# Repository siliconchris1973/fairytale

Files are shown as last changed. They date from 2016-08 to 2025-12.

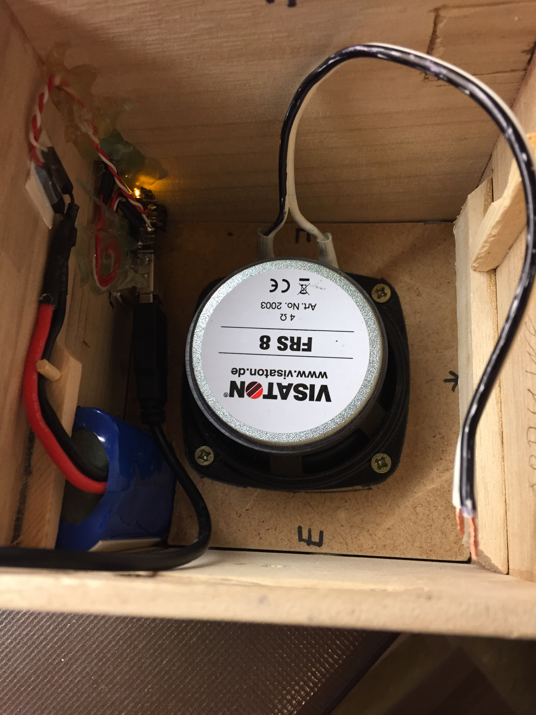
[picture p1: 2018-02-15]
Building Pictures/Inner setup with Loudspeaker, Bat and PowerboostArduino.jpg

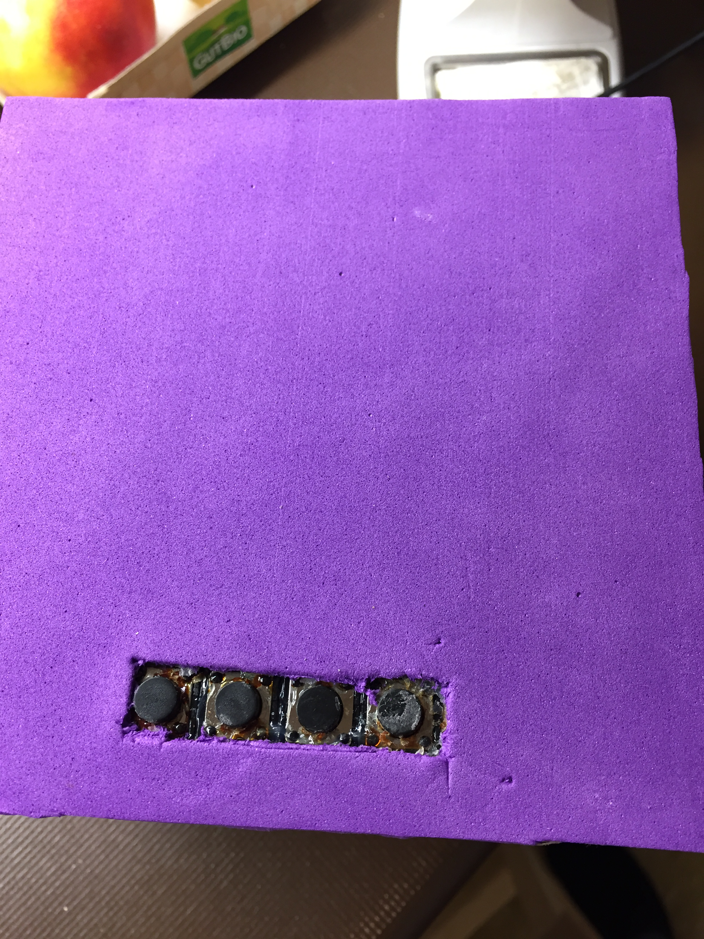
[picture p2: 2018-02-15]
Building Pictures/Top plate with 4 Buttons.jpg

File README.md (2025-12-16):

# fairytale
## Introduction
Fairytale is a mp3-player designed to play audiobooks from an SD Card. The Audiobooks are connected to NFC Tags via the Tag ID, so if you put a Tag on the reader, the corresponding audiobook is played

This tags could for example be attached to little figures - such as Snowhite. Of course you could just put them on little dices or whatever suits you - just keep in mind that my box is supposed to be used by my 4 year old daughter and therefor I use little figures.

The initial version of fairytale ran on an Arduino UNO V3 onto which an Adafruit Music Maker Shield was attached - the code for this version can be found in Arduino_codeline
The version 2 now uses a Raspberry Pi PiCo 2 W (with WLAN) - the code for this version can be found in PiCo_codeline

Furthermore there is a Sunfounder PN532 NFC breakout board attached to it and finally a potentiometer
for volume control and 4 buttons for pause/unpause, next or previous track selection and light effects (turning them on and off).
In version 2 of fairytale an OLED Screen and a RTC clock is included in the setup.
Oh, yes and then of course there is an LED for light effects :-) for warnings and for errors.

## Background
To read the story that initially inspired me to do this project, visit: https://gist.github.com/wkjagt/814b3f62ea03c7b1a765

### Initial (discarded) try Raspberry PI
I started this project off on a Raspberry PI but gave up on it - mainly for three reasons:
1. The Raspberry PI needs way too much time to startup
2. I can't just turn it off because of the danger of damaging the SD Card
3. The volume of the sound output of the RasPi is very limited

All in all, the RasPi approach is not as failsave for a 4 year old, so I gave it up and used the Arduino UNO as the base platform. If you'd nevertheless like to give the RasPi approach a try, you can find the latest state of work in the sub directory RASPI-stuff - be aware though that I never finished it and that there is no guideline on how to build it.

### Version 1 Arduino
NFC controlled MP3 Audiobook Player for my daughter based on an Arduino UNO, Adafruit Music Maker Shield and Sunfounder PN532 NFC Breakout Board.

### Version 2 PiCo
NFC controlled MP3 Audiobook Player for my daughter based on an Raspberry Pi PiCo 2 W, Adafruit Music Maker Shield, Elechouse PN532 NFC Breakout Board V3, DS3231 compatible RTC clokc, SH1106 compatible 128x64 OLED display.

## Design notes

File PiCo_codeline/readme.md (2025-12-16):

# NFC Audio Player für Raspberry Pi Pico
Ein NFC‑gesteuerter Audioplayer auf Basis eines Raspberry Pi Pico, eines Adafruit Music Maker Shields (VS1053 mit SD‑Slot), 
PN532‑NFC‑Reader, SH1106‑OLED und DS3231‑RTC.  
Über einen kleinen HTTP‑Server können im Programmiermodus:
- die RTC Uhr gestellt werden
- ein Verzeichnis unter /audio auf der sd-Karte so umbenannt werden, 
  dass es der Tag UID entspricht - dadurcvh wird dieses Verzeichnis mit dem Tag verknüpft
- Neue Audio-Dateien zu einem aufgelegten Tag auf die SD Karte hochgeladen werden

## Features
- Wiedergabe von MP3‑Dateien über VS1053 vom SD‑Karten‑Dateisystem.
- Steuerung per NFC‑Tags: jedem Tag wird ein „Album“ auf der SD‑Karte zugeordnet - Tag ID = Directory name.
- Programmiermodus (Prog‑Mode) über Hardware‑Schalter und Web‑Interface:
  - WLAN‑Aufbau nur im Prog‑Mode.
  - HTTP‑Upload von Dateien für die aktuell aufgelegte NFC‑UID.
  - Browsen und Löschen von Dateien, Stellen der RTC‑Uhr.
- Persistente Wiedergabestände pro UID (Kapitel, Offset, Volume).
- ID3‑Tag‑Auswertung (Titel, Album, Artist) zur Anzeige im Display.
- Konfigurierbares Debug‑Logging und vielfältige Mock‑Module für Tests (Mock‑NFC, Mock‑Display, Mock‑Audio, Mock‑RTC).

## Hardware
- Raspberry Pi Pico 2 WLAN
- Adafruit Music Maker / VS1053‑Shield 'audio/vs1053.py' (SPI, Audio‑Ausgang) Version von 2017
- PN532‑NFC‑Board (SPI, separates Modul `lib/NFC_PN532.py` plus `nfc/pn532_spi_cargl.py`)
- ZUKÜNFTIG ATTINY, der den PN532 ansteuert und das aktuelle TAG per UART zurückgibt
- SH1106‑OLED (über `display/sh1106_oled.py` und `display/oled_common.py`)
- DS3231‑RTC (I²C) über `rtc/ds3231.py`
- Programmiermodus‑Schalter an `PROG_MODE_PIN` (active low)
- WLAN‑Modul, das durch `net/wifi.py` implementiert wird

Die konkreten Pin‑Belegungen und WLAN‑Zugangsdaten werden in `config.py` konfiguriert.

## Projektstruktur (wichtige Module)
- main.py  
  Initialisiert Hardware, konfiguriert alle Komponenten und übergint sie 
  an den PlayerController. Überwacht den Prog-Mode Butzton und steuert den 
  controller nur an, wenn nicht prog_mode. 
- net/http_server.py / net/web.py
  Kleiner nicht‑blockierender HTTP‑Server mit Endpunkten:
  - `/` – Startseite mit Status, Upload‑Info und Links.
  - `/upload` – GET zeigt Formular, POST nimmt Dateien an (nur wenn `allowed_uid` gesetzt).
  - `/browse` – Verzeichnislisting (Pfad über `path`‑Query).
  - `/delete` – Datei löschen.
  - `/time` – RTC anzeigen/setzen.
  Im Prog-Mode wird von http_server.py der web serbver aufgebaut und von web.py
  die Erzeugung neuer Alben auf der SD Karte und das setzen der RTC Uhr übernommen.
- controller.py
  Zentrale Audio-Ausgabe: kümmert sich um Play/Pause/Next/Prev und die Ausgabe 
  des Fortschritts, der Lautstärke und der Uhr auf dem Display.
  Macxht keine direkte NFC Überprüfung, sondern nutzt dafür ein Trigger-System. 
  Dieses übergibt eine UID, dann play start oder ein stop-signalö, (derzeit Button, 
  zuküünftig Tag weg) für Play Stop.
- storage.py
  Kapselt Dateisystem‑Operationen, u.a. Dateilisten für eine UID, Laden/Speichern von UID‑State, 
  Speichern hochgeladener Dateien.
- vs1053.py / audio.py
  Abstraktion für Audiowiedergabe: `start(path, offset)`, `feed()`, `stop()`, `pause()`, `resume()`, 
  `set_volume()` und Eigenschaften `total_bytes`, `pos_bytes`.
- lib/NFC_PN532.py / nfc/pn532_spi_cargl.py
  Zugriff auf PN532; mindestens `init()` und `read_uid(timeout_ms=...)` werden genutzt.
- display/oled_common.py, display/sh1106.py, display/sh1106_oled.py, display/touch_display.py  
  Display‑Abstraktion, die Funktionen wie `show_status`, `show_play`, `show_stop`, `show_idle`, 
  `show_prog`, `set_time`, `set_date`, `set_volume`, `set_progress_text` etc. bereitstellt.
- buttons.py
  Liest Taster mit Entprellung und liefert Events (`play_pause`, `next`, `prev`, `stop`) über `poll()`. 
  Optionaler Dispatcher.
- volume.py
  Gibt pro Änderung ein Lautstärke‑Delta als Prozentwert zurück (`changed()`) und speichert letzten Wert.
- `ds3231.py`, `rtc.py` / `mock_rtc.py`  
  RTC‑Abstraktion; `rtc.now()` liefert `(y, m, d, wd, hh, mm, ss)`.
- id3.py
  Liest einfache ID3‑Tags aus MP3‑Dateien und liefert ein Dictionary mit `title`, `album`, `artist`, `track` etc.
- config.py
  Zentrale Konfigurationswerte (Pins, Pfade, Debug‑Flags, Prog‑Mode‑Quelle, Zeit‑Konstanten für NFC‑Checks usw.).
- diverse trigger-Dateien
  abstrahiert die Übergabe des Tags von NFC an controller und das setzen eines Stop Events (derzeit per Button)
  um das Beenden der Wiedergabe zu signalisieren

## Installation
1. Repository klonen und Projektdateien auf den Pico (MicroPython) kopieren.
2. `config.py` anpassen:
   - WLAN‑Parameter (SSID, Passwort).
   - Dateipfade (z. B. `AUDIO_ROOT`, `STATE_DIR`).
   - `PROG_MODE_PIN` und `PROG_MODE_SOURCE` („PIN“, „ACTIVE“, „INACTIVE“).
3. SD‑Karte vorbereiten:
   - Basis‑Verzeichnisstruktur wie in `storage.py` vorgesehen anlegen (z. B. pro UID ein Unterordner).
   - Test‑MP3‑Dateien einspielen.
4. Hardware wie in der Konfiguration verdrahten (SPI, I²C, GPIOs).

## Nutzung
### Normalmodus (Audio‑Player)
- Gerät starten.
- OLED zeigt Begrüßung und „Show Tag to play“.
- NFC‑Tag auflegen:
  - NFC IMplementeiorung erkennt neue UID via `nfc.read_uid()` und starte Audfio im Controller.
- Steuerung:
  - Taster: `play_pause`, `next`, `prev`, `stop` (via `buttons.poll()`).
  - Rotary/Volume‑Input: Änderung führt zu `audio.set_volume()` und Anzeige im OLED.
- Fortschritt:
  - `audio.feed()` wird im Hauptloop regelmäßig aufgerufen; Prozentanzeige basiert auf `pos_bytes`/`total_bytes`.
- Tag‑Präsenz wird derzeit nicht geprüft, wird zuküpnftig durch externen MicroController realisiert:
  - Wenn auf ATTINY implementiert, dann wird per UART Tag Weg signalisiert, indem die Tag ID auf NOne gesetzt wird.
    Dies stoppt dann die Audio-Ausgabe.

### Programmiermodus und HTTP‑Upload
- PROG‑Schalter aktivieren (active low, abhängig von `PROG_MODE_SOURCE`).
- Beim Wechsel in den Prog‑Mode:
  - WLAN wird aufgebaut (`wifi.connect()`), IP‑Adresse im Display angezeigt.
  - HTTP‑Server wird „gearmed“ und an `0.0.0.0:UPLOAD_PORT` gebunden.
- NFC‑Tag im Prog‑Mode auflegen:
  - `nfc.read_uid()` im Main Loop liest UID, `active_uid` wird gesetzt und an den HTTP‑Server über `http.arm(uid)` übergeben.
  - Upload ist nun für diese UID freigeschaltet (`allowed_uid`).
- Browser:
  - IP des Geräts im Browser öffnen (z. B. `http://<pico-ip>:<UPLOAD_PORT>/`).
  - Dateien für diese UID hochladen, Verzeichnisse durchsuchen, Dateien löschen und RTC stellen.
- Beim Verlassen des Prog‑Mode:
  - Upload wird deaktiviert, HTTP‑Server optional „disarmed“ und WLAN getrennt.

## Entwicklungs‑ und Testunterstützung
- Mock‑Module (`mock_nfc.py`, `mock_display.py`, `mock_audio.py`, `mock_rtc.py`) erlauben lokale Tests ohne echte Hardware.
- Umfangreiche Debug‑Ausgaben über `_DEBUG_*`‑Flags in `config.py` helfen beim Tracing von NFC‑Events, HTTP‑Requests, Audio‑Timing etc.

## Lizenz
Creative Commons (CC) Lizenz

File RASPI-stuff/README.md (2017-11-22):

# fairytale
## Introduction
Fairytale is a node.js server application designed to play mp3 files (such as
  but of course not limited to audiobooks). You can either control it using
  a rather ugly HTML interface or, which is the intended usage, by RFID or NFC tags.

## Background
To read the story that inspired me to do this, visit: https://gist.github.com/wkjagt/814b3f62ea03c7b1a765

## Installation
To get going issue:

     git clone https://github.com/siliconchris1973/fairytale

     cd fairytale
     cd fairytale-app
     mkdir data/Media
     mkdir data/TagDB
     mkdir data/Cover
     mkdir data/Cover/icon
     mkdir data/Cover/small
     mkdir data/Cover/normal
     npm install

## Dependencies
fairytale depends on
- MPlayer to play the audio files
- libnfc to read the RFID / NFC tags
- node-nfc-daemon to expose libnfc as a websocket

### Install MPlayer
#### Debian (and derivates like Raspbian)
     sudo apt-get install mplayer

#### Mac OS X
     brew install mplayer

### Install libnfc
#### Raspbian
You can either install the libnfc from the distro or compile it from source.
To install the nfc library bundled with Raspbian (Jessie but probably stretch also):

     sudo apt-get libnfc

To compile it from the git source:

     cd ~
     wget http://dl.bintray.com/nfc-tools/sources/libnfc-1.7.1.tar.bz2
     tar -xf libnfc-1.7.1.tar.bz2  
     cd libnfc-1.7.1
     ./configure --prefix=/usr --sysconfdir=/etc
     make
     sudo make install

Create a configuration file:

     cd /etc
     sudo mkdir nfc
     sudo vi /etc/nfc/libnfc.conf

Content of the configuration file (for SPI connection on a Raspberry Pi) is like follows:

     # Allow device auto-detection (default: true)
     # Note: if this auto-detection is disabled, user has to set manually a device
     # configuration using file or environment variable
     allow_autoscan = true

     # Allow intrusive auto-detection (default: false)
     # Warning: intrusive auto-detection can seriously disturb other devices
     # This option is not recommended, user should prefer to add manually his device.
     allow_intrusive_scan = false

     # Set log level (default: error)
     # Valid log levels are (in order of verbosity): 0 (none), 1 (error), 2 (info), 3 (debug)
     # Note: if you compiled with --enable-debug option, the default log level is "debug"
     log_level = 1

     # Manually set default device (no default)
     # To set a default device, you must set both name and connstring for your device
     # Note: if autoscan is enabled, default device will be the first device available in device list.
     device.name = "_PN532_SPI"
     device.connstring = "pn532_spi:/dev/spidev0.0:500000"
     #device.name = "_PN532_I2c"
     #device.connstring = "pn532_i2c:/dev/i2c-1"

#### MacOS X
If you happen to be doing all this on OS X you _may_ need to accept the developers
license for Xcode. Agree to the license terms by executing (in a shell, of
course):

     sudo xcodebuild -license

For libnfc to compile on Mac OS X you will need doxygen, which I recommend you install via brew

     brew install doxygen

Now cd to a convenient directory where you want libnfc source to reside and hack in:

     git clone https://github.com/nfc-tools/libnfc.git
     cd libnfc
     ./configure --enable-doc
     make
     sudo make install

This will install libnfc in /usr/local directory, which I usually do not find to be convenient on OS X, as I can't easily remove it if wanted. Usually I'd prefer to install it in /opt/libnfc, but I couldn't find a way to get node-nfc-daemon to compile on my Mac with libnfc installed below opt, so I put it in /usr/local

Further information on libnfc can be found at
 http://nfc-tools.org/index.php?title=Libnfc

### Install node-nfc-daemon
For information on node-nfc-daemon setEncoding
  https://www.npmjs.com/package/nfc-daemon

#### Raspbian / Mac OS X
     yarn global add nfc-daemon

## Running
fairytale is composed of 6 different services:
1. app.js - main server application
2. player.js - the mp3 player
3. tagDbService.js - an interface to the stored tags with meta data on the mp3 files
4. nfcReader - the nfc reader service
5. fileService.js - upload files (optional you can also do this manually)
6. ledService - drives 3 colored LEDs (optional)

All components are in their respective subdirectory with [App-Name]-app as the directory name.

### Mandatory components
#### app.js
This is the main component. It listens on port 3000 and exposes it's endpoints to /api/v1/... for json and html clients.

To start up the main application with nodemon monitoring execute:

     npm start

To start it manually execute:

     node app.js

#### player.js
The MP3 Player application. It listens on port 3001 and exposes it's endpoint to /api/v1/player for json and html clients.

To start the mp3 player with nodemon monitoring execute:

     npm start

Without nodemon:

     node player.js

#### tagDbService.js
An interface to stored json files that contain the necessary meta data on the nfc tags.
Within each json file a nfc tag and the corresponding mp3 files are described.

To start the TagDB service with nodemon monitoring execute:

     npm start

Without nodemon:

     node tagDbService.js

#### nfcService.js
The RFID and NFC tag reader. It listens on port 3003 and exposes it's endpoint to /api/v1/rfid for json and html clients.

To start the RFID and NFC Reader with nodemon monitoring execute:

     npm start

Without nodemon:

     node nfcService.js

### Optional components
#### ledService.js
The driver for the leds. It listens on port 3005 and exposes it's endpoint to /api/v1/rfid for json and html clients.

To start the LED Service with nodemon monitoring execute:

     npm start

Without nodemon:

     node ledService.js

#### fileService.js
The file uploader only exposes a html formm at the moment and is available on port 3002 at /api/v1/file
To start the optional fileService (for uploading files) execute:

     node fileService.js

## interacting with the application
### via curl on command line

     curl -X GET -H "Content-type: application/json" -H "Accept: application/json"  "http://deepthought.local:3002/api/v1/player/{"id":"0443e222e74c81"}"

## Create Content to play
For the play to actually play a file, two things need to be done:
1. Create a JSON File with information on the mp3 file you want to hear, when you put the tag on the reader
2. Copy the mp3 files in a specific directory.

A typical json file looks like follows:

75EDB4.json:

       {
        "tagdata": {
          "TagChecksum": "0x23",
          "TagId": "75EDB4",
          "TagPreTag": "0xf00",
          "TagRawData": "0F0075EDB423"
        },
        "MediaTitle": "Frederick",
        "MediaType": "Hoerspiel",
        "MediaGenre": "Kindergeschichte",
        "MediaDescription": "Ein Hörspiel mit Musik zu Frederick der kleinen Maus",
        "TrackCount": [
          {"disk": "1", "tracks": "1"}
        ],
        "DiskCount": "1",
        "MediaFiles": [{
          "disk": "1",
          "part": "1",
          "id": "75EDB4:d1:p1",
          "name": "Frederick.mp3",
          "path": "Media/Disk_1/Frederick.mp3",
          "lastposition": "-1",
          "playcount": "0",
          "size": "24M"
        }],
        "MediaPicture": [{
          "pic": "1",
          "name": "Frederick.jpg",
          "path": "Cover/normal/Frederick.jpg"
        }]
       }

As you can see, you can have multiple mp3 files associated with a tag and the player
will play all files in the given order - you can also split files in disks.

To make registering a new tag with it's files easier, I will include a page to aid in the process.
Currently, when you have a new tag and want to associate it with mp3-files you will need
to do the following:

- copy/create a json file in the data/TagDB directory. The name of the file needs to match the UUID
- make a new directory with the UUID of the nfc tag below data/Media - the directory name should be all upper case
- copy all mp3-files in the sub directories you used within the json file in the path section.

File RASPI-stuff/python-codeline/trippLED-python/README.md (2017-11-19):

# trippLED
# # Description
A simple python app to drive 3 differntly colored leds (here red, green and blue) via a REST API.

# Installation
Is installed automatically with the rest of the fairytale applications, but there are a few Dependencies.

## Dependencies:
### flask
sudo pip install flask

### flask-restful
sudo pip install flask-restful

# Run
python cycLED.py

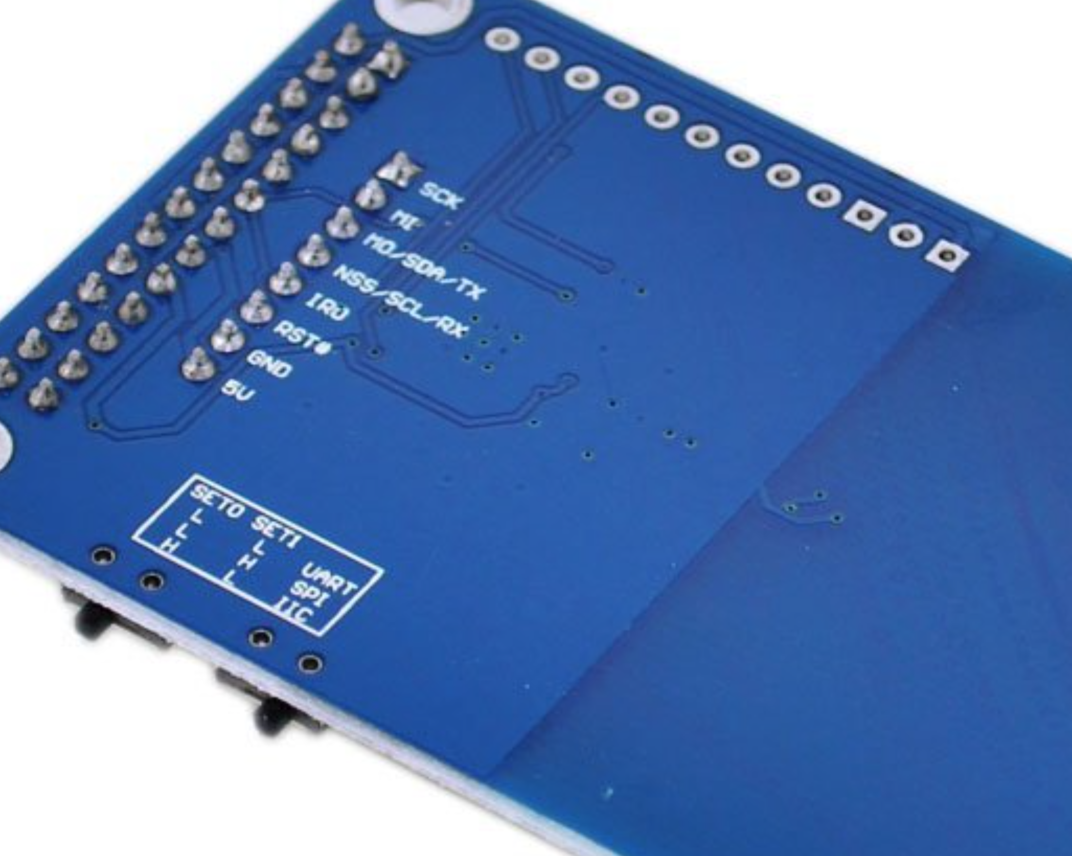
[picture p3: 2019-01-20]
3rd Party Schematics/Pinout Sunfounder PN532 NFC module.png

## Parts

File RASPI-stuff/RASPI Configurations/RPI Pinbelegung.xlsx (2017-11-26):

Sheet: Pinbelegung Template
Anschlussplan für Verbindung Raspberry PI mit Nokia5110, Tasterleiste und Distance
 |  |  |  |  | Pins von |  |  |  | oben |  | zählen
Zusatz |  | Kabel | Anschluss- |  |  | Raspberry PI |  |  |  |  |  |  |  |  |  | Anschluss- | Kabel |  | Zusatz |  |  |  |  | Farben | Anzahl belegter Ports |  |  |  |  | Kabel linke Seite |  |  |  |  |  |  |  |  |  |  |  |  | Kabel rechte Seite
Info | Ziel | Farbe | Ziel / Typ | 7 |  |  |  | 5 |  |  | 4 |  |  |  | 5 | Ziel / Typ | Farbe | Ziel | Info |  |  |  | Bauteile | Kabel- | Linke Seite | Rechte Seite | GPIO links | GPIO rechts | Summe | 1 | 0 | 0 | 1 | 0 | 0 | 1 | 0 | 0 | 0 | 0 | 0 | 0 | 0 | 0 | 0 | 0 | 0 | 1 | 1 | 0 | 1 | 1 | 0 | 0 | 0 | Text
 |  |  |  |  |  |  | Typ | GPIO | Pin # |  | GPIO | Typ |  |  |  |  |  |  |  |  |  |  | + Geräte | Farben | 7 | 5 | 5 | 4 |  | Rot | Orange | Gelb | Grün | Blau | Lila | Weiss | Grau | Braun | Schwarz | Gestreift | mit Naht | Anders | Rot | Orange | Gelb | Grün | Blau | Lila | Weiss | Grau | Braun | Schwarz | Gestreift | mit Naht | Anders
Plus Backlight | Nokia5110 | Rot | VCC 3.3v | <-- | 1 | v | 3.3v |  | 1 | 2 |  | 5v | v |  |  |  |  |  |  | 1 | 20 | 1 | Nokia5110 | Rot | 1 | 0 | 0 | 0 | 1 | 1 | 0 | 0 | 0 | 0 | 0 | 0 | 0 | 0 | 0 | 0 | 0 | 0 | 0 | 0 | 0 | 0 | 0 | 0 | 0 | 0 | 0 | 0 | 0 | 0 | 0 | 1 Rot
 |  |  |  |  |  | I2C | SDA | 02 | 3 | 4 |  | 5v | v |  |  |  |  |  |  | 2 | 19 | 2 | Tasterleiste | Orange | 0 | 0 | 0 | 0 | 0 | 0 | 0 | 0 | 0 | 0 | 0 | 0 | 0 | 0 | 0 | 0 | 0 | 0 | 0 | 0 | 0 | 0 | 0 | 0 | 0 | 0 | 0 | 0 | 0 | 0 | 0 | keines Orange
 |  |  |  |  |  |  | SCL | 03 | 5 | 6 |  | GND | g | 3 | --> | Ground | Schwarz | Nokia5110 |  | 3 | 18 | 3 | Distance | Gelb | 0 | 1 | 0 | 0 | 0 | 0 | 0 | 0 | 0 | 0 | 0 | 0 | 0 | 0 | 0 | 0 | 0 | 0 | 0 | 0 | 0 | 0 | 0 | 0 | 0 | 0 | 0 | 1 | 0 | 0 | 0 | keines Gelb
 |  |  |  |  |  |  |  | 04 | 7 | 8 | 14 | TXD | UART |  |  |  |  |  |  | 4 | 17 | 4 | LED | Grün | 0 | 0 | 0 | 0 | 1 | 0 | 0 | 0 | 0 | 0 | 0 | 0 | 0 | 0 | 0 | 0 | 0 | 0 | 0 | 0 | 0 | 0 | 0 | 0 | 0 | 0 | 0 | 0 | 0 | 0 | 0 | 1 Grün
 |  |  |  |  |  | g | GND |  | 9 | 10 | 15 | RXD |  |  |  |  |  |  |  | 5 | 16 | 5 | Schalter | Blau | 0 | 0 | 0 | 0 | 0 | 0 | 0 | 0 | 0 | 0 | 0 | 0 | 0 | 0 | 0 | 0 | 0 | 0 | 0 | 0 | 0 | 0 | 0 | 0 | 0 | 0 | 0 | 0 | 0 | 0 | 0 | keines Blau
 | Distance | Weiss | Trigger | <-- | 6 |  |  | 17 | 11 | 12 | 18 | PCM_CLK |  | 6 | --> | Echo | Braun | Distance |  | 6 | 15 | 6 | Poti | Lila | 1 | 1 | 1 | 1 | 1 | 0 | 0 | 0 | 0 | 0 | 0 | 1 | 0 | 0 | 0 | 0 | 0 | 0 | 0 | 0 | 0 | 0 | 0 | 0 | 0 | 0 | 1 | 0 | 0 | 0 | 0 | 1 Lila
 |  |  |  |  |  |  |  | 27 | 13 | 14 |  | GND | g |  |  |  |  |  |  | 7 | 14 | 7 | VCC 5v | Weiss | 0 | 0 | 0 | 0 | 2 | 0 | 0 | 0 | 0 | 0 | 0 | 0 | 0 | 0 | 0 | 0 | 0 | 0 | 0 | 0 | 0 | 0 | 0 | 0 | 0 | 0 | 0 | 0 | 0 | 0 | 0 | 2 Weiss
 |  |  |  |  |  |  |  | 22 | 15 | 16 | 23 |  |  | 8 | --> | DC | Weiss | Nokia5110 |  | 8 | 13 | 8 | VCC 3.3v | Grau | 0 | 1 | 0 | 1 | 0 | 0 | 0 | 0 | 0 | 0 | 0 | 0 | 0 | 0 | 0 | 0 | 0 | 0 | 0 | 0 | 0 | 0 | 0 | 0 | 1 | 0 | 0 | 0 | 0 | 0 | 0 | keines Grau
 |  |  |  |  |  | v | 3.3v |  | 17 | 18 | 24 |  |  | 9 | --> | Reset | Lila | Nokia5110 | RST | 9 | 12 | 9 | Reset | Braun | 0 | 1 | 0 | 1 | 1 | 0 | 0 | 0 | 0 | 0 | 0 | 0 | 0 | 0 | 0 | 0 | 0 | 0 | 0 | 0 | 0 | 0 | 0 | 1 | 0 | 0 | 0 | 0 | 0 | 0 | 0 | 1 Braun
 | Nokia5110 | Grün | DIN | <-- | 10 | SPI | MOSI | 10 | 19 | 20 |  | GND | g |  |  |  |  |  |  | 10 | 11 | 10 | Power | Schwarz | 1 | 0 | 1 | 0 | 1 | 0 | 0 | 0 | 1 | 0 | 0 | 0 | 0 | 0 | 0 | 0 | 0 | 0 | 0 | 0 | 0 | 0 | 0 | 0 | 0 | 0 | 0 | 0 | 0 | 0 | 0 | 1 Schwarz
 |  |  |  |  |  |  | MISO | 09 | 21 | 22 | 25 |  |  |  |  |  |  |  |  | 11 | 10 | 11 | Ground | Gestreift | 0 | 0 | 0 | 0 | 0 | 0 | 0 | 0 | 0 | 0 | 0 | 0 | 0 | 0 | 0 | 0 | 0 | 0 | 0 | 0 | 0 | 0 | 0 | 0 | 0 | 0 | 0 | 0 | 0 | 0 | 0 | keines Gestreift
CLK | Nokia5110 | Blau | Clock | <-- | 12 |  | SCLK | 11 | 23 | 24 | 08 | CE0 | SPI | 12 | --> | CE | Grau | Nokia5110 |  | 12 | 9 | 12 | Daten | mit Naht | 1 | 1 | 1 | 1 | 0 | 0 | 0 | 0 | 0 | 1 | 0 | 0 | 0 | 0 | 0 | 0 | 0 | 0 | 0 | 0 | 0 | 0 | 0 | 0 | 0 | 1 | 0 | 0 | 0 | 0 | 0 | keines mit Naht
 |  |  |  |  |  | g | GND |  | 25 | 26 | 07 | CE1 |  |  |  |  |  |  |  | 13 | 8 | 13 | Clock | Anders | 0 | 0 | 0 | 0 | 0 | 0 | 0 | 0 | 0 | 0 | 0 | 0 | 0 | 0 | 0 | 0 | 0 | 0 | 0 | 0 | 0 | 0 | 0 | 0 | 0 | 0 | 0 | 0 | 0 | 0 | 0 | keines Anders
 |  |  |  |  |  |  | ID_SD |  | 27 | 28 |  | ID_SC |  |  |  |  |  |  |  | 14 | 7 | 14 | Backlight |  | 0 | 0 | 0 | 0 |  |  |  |  |  |  |  |  |  |  |  |  |  |  |  |  |  |  |  |  |  |  |  |  |  |  |  | 1 Rot, keines Orange, keines Gelb, 1 Grün, keines Blau, 1 Lila, 2 Weiss, keines Grau, 1 Braun, 1 Schwarz, keines Gestreift, keines mit Naht und keines Anders
 |  |  |  |  |  |  |  | 05 | 29 | 30 |  | GND | g |  |  |  |  |  |  | 15 | 6 | 15 | Trigger |  | 0 | 0 | 0 | 0
 |  |  |  |  |  |  |  | 06 | 31 | 32 | 12 |  |  |  |  |  |  |  |  | 16 | 5 | 16 | Echo |  | 0 | 0 | 0 | 0
 |  |  |  |  |  |  |  | 13 | 33 | 34 |  | GND | g |  |  |  |  |  |  | 17 | 4 | 17 |  |  | 0 | 0 | 0 | 0
Funktion | Tasterleiste | Braun | Power | <-- | 18 |  |  | 19 | 35 | 36 | 16 |  |  |  |  |  |  |  |  | 18 | 3 | 18 |  |  | 1 | 0 | 1 | 0
Funktion | Tasterleiste | Braun | Reset | <-- | 19 |  |  | 26 | 37 | 38 | 20 |  |  |  |  |  |  |  |  | 19 | 2 | 19 |  |  | 1 | 0 | 1 | 0
 | Tasterleiste | Schwarz | Ground | <-- | 20 | g | GND |  | 39 | 40 | 21 |  |  |  |  |  |  |  |  | 20 | 1 | 20 |  |  | 1 | 0 | 0 | 0
 |  |  |  |  |  | USB und LAN Anschlüsse
Zum Anschluss des Nokia5110 an den Raspberry PI werden 12 Kabel benötigt (7 auf der linken und 5 auf der rechten Seite) und 9 GPIO-Ports sind nach Anschluss belegt. Von den 12 Kabeln sind 1 Rot, keines Orange, keines Gelb, 1 Grün, keines Blau, 1 Lila, 2 Weiss, keines Grau, 1 Braun, 1 Schwarz, keines Gestreift, keines mit Naht und keines Anders farbig |  |  |  |  |  |  |  |  |  |  |  |  |  |  |  |  |  |  |  |  |  |  | TRX
 |  |  |  |  |  |  |  |  |  |  |  |  |  |  |  |  |  |  |  |  |  |  | RXD
 |  |  |  |  |  |  |  |  |  |  |  |  |  |  |  |  |  |  |  |  |  |  | SDA
 |  |  |  |  |  |  |  |  |  |  |  |  |  |  |  |  |  |  |  |  |  |  | SCL
 |  |  |  |  |  |  |  |  |  |  |  |  |  |  |  |  |  |  |  |  |  |  | DC
 |  |  |  |  |  |  |  |  |  |  |  |  |  |  |  |  |  |  |  |  |  |  | CE
 |  |  |  |  |  |  |  |  |  |  |  |  |  |  |  |  |  |  |  |  |  |  | DIN
 |  |  |  |  |  |  |  |  |  |  |  |  |  |  |  |  |  |  |  |  |  |  | PCM

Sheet: Pinbelegung Nokia5110-NFC532
Anschlussplan für Verbindung Raspberry PI mit NFC532 und Nokia5110
 |  |  |  |  | Pins von |  |  |  | oben |  | zählen
Zusatz |  | Kabel | Anschluss- |  |  | Raspberry PI |  |  |  |  |  |  |  |  |  | Anschluss- | Kabel |  | Zusatz |  |  |  |  | Farben | Anzahl belegter Ports |  |  |  |  | Kabel linke Seite |  |  |  |  |  |  |  |  |  |  |  |  | Kabel rechte Seite
Info | Ziel | Farbe | Ziel / Typ | 7 |  |  |  | 5 |  |  | 6 |  |  |  | 9 | Ziel / Typ | Farbe | Ziel | Info |  |  |  | Bauteile | Kabel- | Linke Seite | Rechte Seite | GPIO links | GPIO rechts | Summe | 1 | 1 | 0 | 0 | 0 | 0 | 0 | 0 | 0 | 0 | 0 | 0 | 0 | 1 | 1 | 0 | 0 | 0 | 0 | 0 | 0 | 1 | 1 | 0 | 0 | 0 | Text
 |  |  |  |  |  |  | Typ | GPIO | Pin # |  | GPIO | Typ |  |  |  |  |  |  |  |  |  |  | + Geräte | Farben | 7 | 9 | 5 | 6 |  | Rot | Orange | Gelb | Grün | Blau | Lila | Weiss | Grau | Braun | Schwarz | Gestreift | mit Naht | Anders | Rot | Orange | Gelb | Grün | Blau | Lila | Weiss | Grau | Braun | Schwarz | Gestreift | mit Naht | Anders
 | Nokia5110 | Orange | VCC 3.3v | <-- | 1 | v | 3.3v |  | 1 | 2 |  | 5v | v | 1 | --> | VCC 5v | Rot | NFC532 |  | 1 | 20 | 1 | NFC532 | Rot | 1 | 1 | 0 | 0 | 2 | 0 | 1 | 0 | 0 | 0 | 0 | 0 | 0 | 0 | 0 | 0 | 0 | 0 | 1 | 0 | 0 | 0 | 0 | 0 | 0 | 0 | 0 | 0 | 0 | 0 | 0 | 2 Rot
 |  |  |  |  |  | I2C | SDA | 02 | 3 | 4 |  | 5v | v |  |  |  |  |  |  | 2 | 19 | 2 | Nokia5110 | Orange | 0 | 0 | 0 | 0 | 2 | 0 | 0 | 0 | 0 | 0 | 0 | 0 | 0 | 0 | 0 | 0 | 0 | 0 | 0 | 0 | 0 | 0 | 0 | 0 | 0 | 0 | 0 | 0 | 0 | 0 | 0 | 2 Orange
 |  |  |  |  |  |  | SCL | 03 | 5 | 6 |  | GND | g | 3 | --> | Ground | Schwarz |  | für alles | 3 | 18 | 3 |  | Gelb | 0 | 1 | 0 | 0 | 0 | 0 | 0 | 0 | 0 | 0 | 0 | 0 | 0 | 0 | 0 | 0 | 0 | 0 | 0 | 0 | 0 | 0 | 0 | 0 | 0 | 0 | 0 | 1 | 0 | 0 | 0 | keines Gelb
 |  |  |  |  |  |  |  | 04 | 7 | 8 | 14 | TXD | UART |  |  |  |  |  |  | 4 | 17 | 4 | LED | Grün | 0 | 0 | 0 | 0 | 0 | 0 | 0 | 0 | 0 | 0 | 0 | 0 | 0 | 0 | 0 | 0 | 0 | 0 | 0 | 0 | 0 | 0 | 0 | 0 | 0 | 0 | 0 | 0 | 0 | 0 | 0 | keines Grün
 |  |  |  |  |  | g | GND |  | 9 | 10 | 15 | RXD |  |  |  |  |  |  |  | 5 | 16 | 5 | Schalter | Blau | 0 | 0 | 0 | 0 | 0 | 0 | 0 | 0 | 0 | 0 | 0 | 0 | 0 | 0 | 0 | 0 | 0 | 0 | 0 | 0 | 0 | 0 | 0 | 0 | 0 | 0 | 0 | 0 | 0 | 0 | 0 | keines Blau
 |  |  |  |  |  |  |  | 17 | 11 | 12 | 18 | PCM_CLK |  |  |  |  |  |  |  | 6 | 15 | 6 | Poti | Lila | 0 | 0 | 0 | 0 | 0 | 0 | 0 | 0 | 0 | 0 | 0 | 0 | 0 | 0 | 0 | 0 | 0 | 0 | 0 | 0 | 0 | 0 | 0 | 0 | 0 | 0 | 0 | 0 | 0 | 0 | 0 | keines Lila
 |  |  |  |  |  |  |  | 27 | 13 | 14 |  | GND | g |  |  |  |  |  |  | 7 | 14 | 7 | VCC 5v | Weiss | 0 | 0 | 0 | 0 | 0 | 0 | 0 | 0 | 0 | 0 | 0 | 0 | 0 | 0 | 0 | 0 | 0 | 0 | 0 | 0 | 0 | 0 | 0 | 0 | 0 | 0 | 0 | 0 | 0 | 0 | 0 | keines Weiss
 |  |  |  |  |  |  |  | 22 | 15 | 16 | 23 |  |  | 8 | --> | DC | Braun | Nokia5110 |  | 8 | 13 | 8 | VCC 3.3v | Grau | 0 | 1 | 0 | 1 | 0 | 0 | 0 | 0 | 0 | 0 | 0 | 0 | 0 | 0 | 0 | 0 | 0 | 0 | 0 | 0 | 0 | 0 | 0 | 0 | 0 | 0 | 1 | 0 | 0 | 0 | 0 | keines Grau
 |  |  |  |  |  | v | 3.3v |  | 17 | 18 | 24 |  |  | 9 | --> | Reset | Orange | Nokia5110 |  | 9 | 12 | 9 | Reset | Braun | 0 | 1 | 0 | 1 | 1 | 0 | 0 | 0 | 0 | 0 | 0 | 0 | 0 | 0 | 0 | 0 | 0 | 0 | 0 | 1 | 0 | 0 | 0 | 0 | 0 | 0 | 0 | 0 | 0 | 0 | 0 | 1 Braun
 | Nokia5110 | Rot | DIN DataIn | <-- | 10 | SPI | MOSI | 10 | 19 | 20 |  | GND | g |  |  |  |  |  |  | 10 | 11 | 10 | Power | Schwarz | 1 | 0 | 1 | 0 | 1 | 1 | 0 | 0 | 0 | 0 | 0 | 0 | 0 | 0 | 0 | 0 | 0 | 0 | 0 | 0 | 0 | 0 | 0 | 0 | 0 | 0 | 0 | 0 | 0 | 0 | 0 | 1 Schwarz
 |  |  |  |  |  |  | MISO | 09 | 21 | 22 | 25 |  |  |  |  |  |  |  |  | 11 | 10 | 11 | Ground | Gestreift | 0 | 0 | 0 | 0 | 0 | 0 | 0 | 0 | 0 | 0 | 0 | 0 | 0 | 0 | 0 | 0 | 0 | 0 | 0 | 0 | 0 | 0 | 0 | 0 | 0 | 0 | 0 | 0 | 0 | 0 | 0 | keines Gestreift
 | Nokia5110 | Lila | CLK | <-- | 12 |  | SCLK | 11 | 23 | 24 | 08 | CE0 | SPI | 12 | --> | CS bzw. CE | Blau | Nokia5110 |  | 12 | 9 | 12 | Daten | mit Naht | 1 | 1 | 1 | 1 | 0 | 0 | 0 | 0 | 0 | 0 | 1 | 0 | 0 | 0 | 0 | 0 | 0 | 0 | 0 | 0 | 0 | 0 | 1 | 0 | 0 | 0 | 0 | 0 | 0 | 0 | 0 | keines mit Naht
 |  |  |  |  |  | g | GND |  | 25 | 26 | 07 | CE1 |  |  |  |  |  |  |  | 13 | 8 | 13 | Clock | Anders | 0 | 0 | 0 | 0 | 0 | 0 | 0 | 0 | 0 | 0 | 0 | 0 | 0 | 0 | 0 | 0 | 0 | 0 | 0 | 0 | 0 | 0 | 0 | 0 | 0 | 0 | 0 | 0 | 0 | 0 | 0 | keines Anders
 |  |  |  |  |  |  | ID_SD |  | 27 | 28 |  | ID_SC |  |  |  |  |  |  |  | 14 | 7 | 14 | Backlight |  | 0 | 0 | 0 | 0 |  |  |  |  |  |  |  |  |  |  |  |  |  |  |  |  |  |  |  |  |  |  |  |  |  |  |  | 2 Rot, 2 Orange, keines Gelb, keines Grün, keines Blau, keines Lila, keines Weiss, keines Grau, 1 Braun, 1 Schwarz, keines Gestreift, keines mit Naht und keines Anders
 |  |  |  |  |  |  |  | 05 | 29 | 30 |  | GND | g |  |  |  |  |  |  | 15 | 6 | 15 | Trigger |  | 0 | 0 | 0 | 0
 |  |  |  |  |  |  |  | 06 | 31 | 32 | 12 |  |  | 16 | --> | Backlight | Orange | Nokia5110 | Hintergrundbeleuchtung | 16 | 5 | 16 | Echo |  | 0 | 1 | 0 | 1
Tripple LED - ROT |  |  | LED | <-- | 17 |  |  | 13 | 33 | 34 |  | GND | g | 17 | --> | Ground |  |  | Dual-Switch | 17 | 4 | 17 |  |  | 1 | 1 | 1 | 0
Tripple LED - GRÜN |  |  | LED | <-- | 18 |  |  | 19 | 35 | 36 | 16 |  |  | 18 | --> | Schalter |  |  | Switch 1 | 18 | 3 | 18 |  |  | 1 | 1 | 1 | 1
Tripple LED - BLAU |  |  | LED | <-- | 19 |  |  | 26 | 37 | 38 | 20 |  |  | 19 | --> | Schalter |  |  | Switch 2 | 19 | 2 | 19 |  |  | 1 | 1 | 1 | 1
Tripple LED |  |  | Ground | <-- | 20 | g | GND |  | 39 | 40 | 21 |  |  |  |  |  |  |  |  | 20 | 1 | 20 |  |  | 1 | 0 | 0 | 0
 |  |  |  |  |  | USB und LAN Anschlüsse
Zum Anschluss des NFC532 an den Raspberry PI werden 16 Kabel benötigt (7 auf der linken und 9 auf der rechten Seite) und 11 GPIO-Ports sind nach Anschluss belegt. Von den 16 Kabeln sind 2 Rot, 2 Orange, keines Gelb, keines Grün, keines Blau, keines Lila, keines Weiss, keines Grau, 1 Braun, 1 Schwarz, keines Gestreift, keines mit Naht und keines Anders farbig |  |  |  |  |  |  |  |  |  |  |  |  |  |  |  |  |  |  |  |  |  |  | CLK
 |  |  |  |  |  |  |  |  |  |  |  |  |  |  |  |  |  |  |  |  |  |  | CS
 |  |  |  |  |  |  |  |  |  |  |  |  |  |  |  |  |  |  |  |  |  |  | SDA
 |  |  |  |  |  |  |  |  |  |  |  |  |  |  |  |  |  |  |  |  |  |  | SCL
 |  |  |  |  |  |  |  |  |  |  |  |  |  |  |  |  |  |  |  |  |  |  | DC
 |  |  |  |  |  |  |  |  |  |  |  |  |  |  |  |  |  |  |  |  |  |  | CE
 |  |  |  |  |  |  |  |  |  |  |  |  |  |  |  |  |  |  |  |  |  |  | DIN DataIn
 |  |  |  |  |  |  |  |  |  |  |  |  |  |  |  |  |  |  |  |  |  |  | PCM
 |  |  |  |  |  |  |  |  |  |  |  |  |  |  |  |  |  |  |  |  |  |  | CS bzw. CE

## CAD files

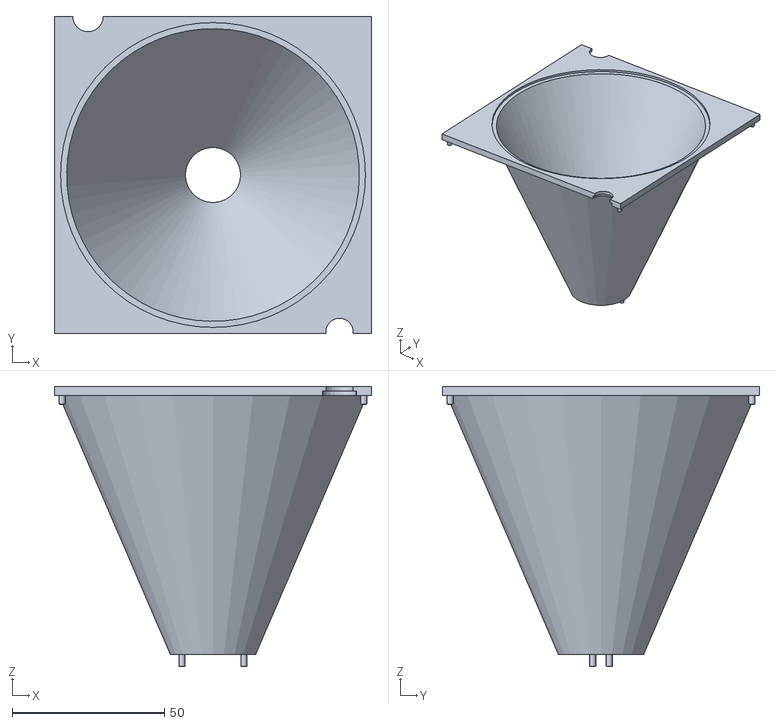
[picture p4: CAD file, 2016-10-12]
3D Model/conical_cylinder_11cm.stl
104.0 x 104.0 x 92.0

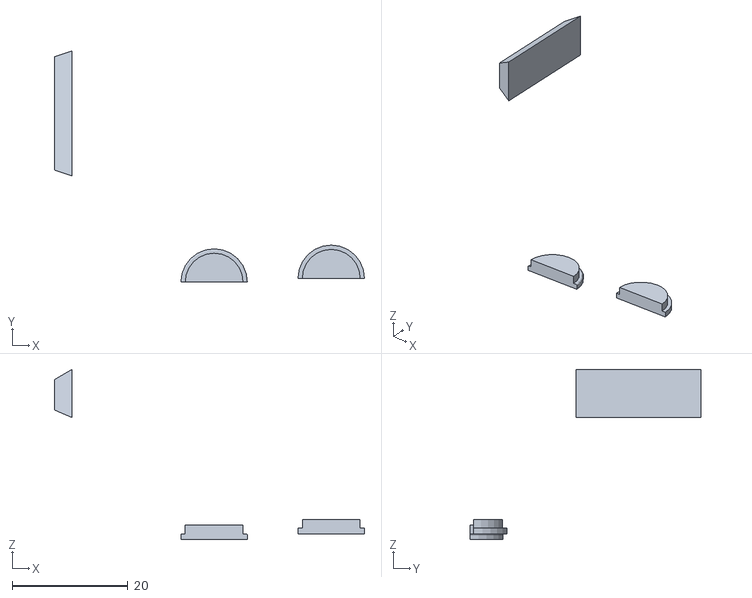
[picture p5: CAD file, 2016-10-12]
3D Model/rubber_inlets.stl
53.6 x 40.0 x 29.4

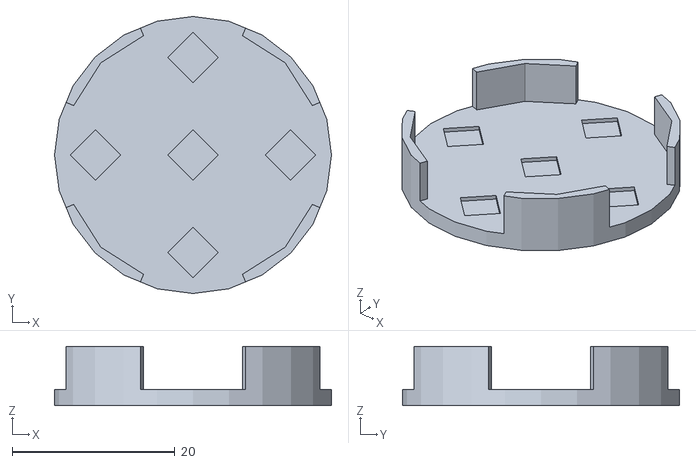
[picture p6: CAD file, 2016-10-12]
3D Model/buttons_holder.stl
34.0 x 34.0 x 7.30

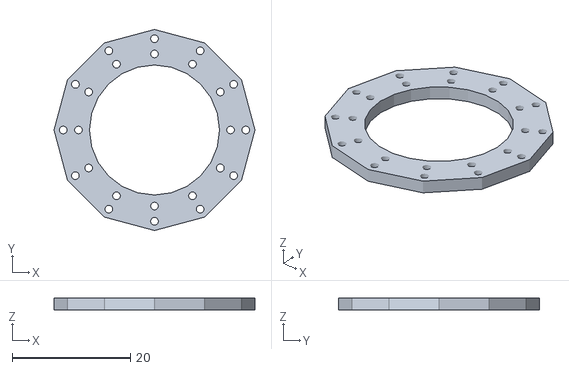
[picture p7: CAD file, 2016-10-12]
3D Model/LED_Ring.stl
34.0 x 34.0 x 2.00

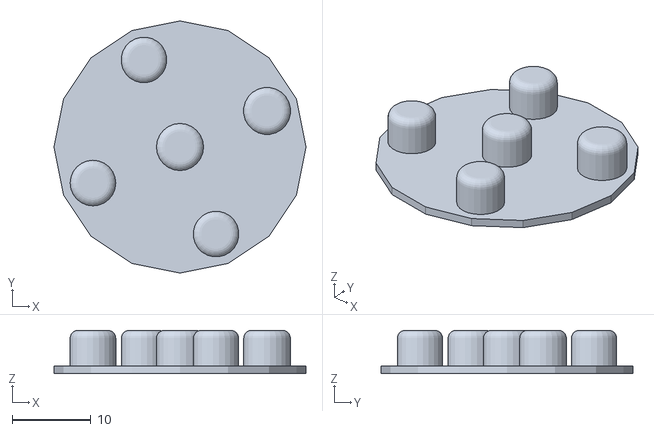
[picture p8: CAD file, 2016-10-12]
3D Model/buttons_disc.stl
32.0 x 32.0 x 5.50

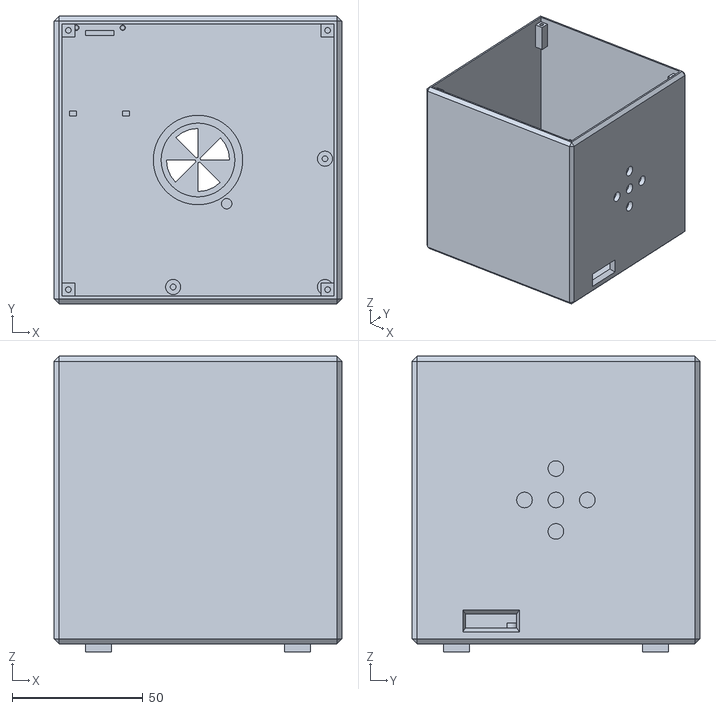
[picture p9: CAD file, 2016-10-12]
3D Model/Cube-11cm-Plain.stl
110.0 x 110.0 x 113.0

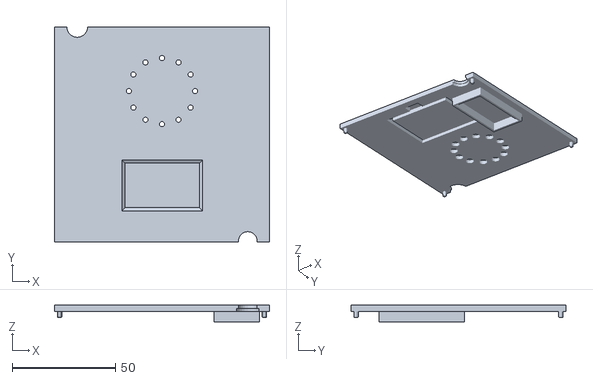
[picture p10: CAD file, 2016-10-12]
3D Model/plain_top_plate_11cm.stl
104.0 x 104.0 x 8.00

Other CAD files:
3D Model/rfid_top_plate_11cm.stl
3D Model/Cube-11cm-Plain.skp
3D Model/LED_Ring.skp
3D Model/buttons_disc.skp
3D Model/buttons_holder.skp
3D Model/conical_cylinder_11cm.skp
3D Model/rfid_top_plate_11cm.skp
3D Model/rfid_top_plate_11cm~.skp
3D Model/rubber_inlets.skp

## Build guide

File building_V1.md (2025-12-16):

# Building Fairytale V1
Following one may find the a (hopefully) complete step by step instruction on how to build Fairytale.

## Hardware design
This section explains components and hardware layout as well of wiring the different components that make up Fairytale.

### Components
- Arduino UNO V3
- Adafruit Music Maker Shield
- Sunfounder PN532 NFC Reader
- Adafruit Powerboost 1000c
- 3W Speaker - Mine is quite big as can be seen in the pictures but of course you could use any speaker that fits you. Just make sure it can handle the 3 watts output of the Adafruit Music Maker Shield.
- LiPo Battery - I have a very big battery and that is good, as it gives plenty of playback time.
- 5 Push buttons - 4 to control the operation and one to program a new tag.
- 3 LEDs - 1 operations light, 1 warning and 1 error light
- 1 Potentiometer for volume control
- Wires to connect everything together
- Hot Glue to attach all the stuff in the box
- Box - Mine is wooden but I also have a 3D model for a plastic box

### Hardware layout
All components are of course put into a "little" box - mine is made of wood and I bought it from shelf. I dismantled the top lit and exchanged that with a plain plate of same size.

#### Speaker
The speaker is directed to the bottom but slightly above the bottom of the box - roughly a centimeter from it. I attached the speaker to a wooden square with a hole the size of the speaker, attached 4 pillars to it to raise this square from the box' bottom. I also created an opening in the bottom of the box and attached some fiber to shield the speaker. Finally I put 4 pillars to the bottom of the box to raise it from ground.

To be honest, this whole layout is a very unfortunate design choice, as the sound is not that strong and clear as it could be. If I'd had it directed to the front, of course the sound would have been stronger and possibly not as muffled, but I wanted to have the volume control (see below) to stick out of the front).

#### NFC Reader
The NFC Reader is attached to the underside of the top of the box and the top itself is fixed to the box via small nails. I also carved out an oblong opening in this top plate to make room for the 4 buttons. The buttons are again fixed to the top plate by means of a small piece of wood glued to the plate - see pictures here.

#### Adafruit Powerboost 1000c / LiPo Battery
The Adafruit Powerboost 1000c is glued to on side very low to the bottom of the box and the battery is standing upright in the front left corner. For this I had to create a small opening in the plate that supports the speaker.

#### Arduino / Music Maker Shield
Opposite the battery the Arduino UNO with attached Adafruit Music Maker Shield is glued to the box. This allows for a small opening on the back of the box. This opening can be used to retrieve and insert the SD card from / into the Music Maker Shield and it also gives access to the USB port for programming purposes of the Arduino - all this without the need to open the top plate of the box.

#### Buttons
The 4 buttons (see below) are on the top plate and the volume control pot is on the front.

#### Lights
Also on the front is the operations light, whereas the Error light (also used for LBO) is on the back. The warning LED is on the left side. You can see my design in the pictures.

### Control Buttons
The Fairytale audiobook reader box design comes with 4 buttons to control operation:
- pause / unpause     - pauses the playback or unpauses a paused playback
- next                - play the next track in a consecutive list of ordered files
- previous            - play the previous track in a consecutive list of ordered files
- light on / off      - turn the operations light fader on or off

Additionally there is a programming button (A3 see below) included that will change the program in such a way that it will wait for a "new" tag, ask for a directory and track number to associate with this tag and will update the TrackDb accordingly. For this to work the box of course would need to be connected to the Arduino IDE and the serial console must be active. Functionality is not yet implemented)

All 4 control buttons are attached to only one analog pin (here A1). To distinguish which button was pressed, I made sure every button has a resistor with a different Ohm attached to it's input pin. I used:
- 33 Ohm
- 220 Ohm
- 330 Ohm
- 1 KOhm

### Volume Control
A potentiometer connected to analog input pin A0 on the Arduino is used for volume control. While playing a track the program checks for changes on the potentiometer and calculates the corresponding volume from the level of the pot.

### Used Pins of the Arduino UNO:
Quite a few, if not nearly all, of the pins of the Arduino are used up.

#### SPI
- 13 : CLK / PN532_SCK : SPI Clock shared with VS1053, SD card and NFC breakout board
- 12 : MISO / PN532_MISO : Input data from VS1053, SD card and NFC breakout board
- 11 : MOSI / PN532_MOSI : Output data to VS1053, SD card and NFC breakout board

#### VS1053 Music Maker Shield
- 7 : SHIELD_CS : VS1053 chip select pin (output)
- 6 : SHIELD_DCS : VS1053 Data/command select pin (output)
- 3 : DREQ : VS1053 Data request, ideally an Interrupt pin

#### SD Card
- 4 CARDCS : SD Card chip select pin

#### PN532 NFC Reader
- 10 : PN532_SS : NFC breakout board chip select pin

#### LEDs
- 5 : ledPin : the pin to which the operation led is connected to
- 8 : warnPin : the pin to which the warning led is connected to
- 9 errorPin : the pin to which the error led is connected to (e.g. used for LBO of powerboost 1000c)

#### Input Buttons etc.
- A0 : volumePotPin : the analog input pin that we use for the potentiometer
- A1 : btnLinePin : pin to which the button line (4 buttons) is connected to
- A2 : batLowInputPin : the pin on which the powerboost 1000c indicates a low battery (LBO) - ouput done via errorPin (not yet implemented)
- A3 : programming : the pin the program button is connected to (not yet implemented).

### Putting all together
#### Power line duplicator
The Arduino has very limited power and ground output pins, so I decided to get +5V and +3V and Ground from the Adafruit Powerboost and have a little "power line duplicator" - This power line duplicator is essentially a little (3cm x 1,5cm) plate onto which a couple of male headers are attached which are connected to +5V, +3V and GND of the Powerboost - This gives me 5 pins for +5V, 5 pins for +3V and also 5 pins for Ground.

To this "power line duplicator" I attached all external components that needed plus voltage and ground - such as the PN532 NFC Reader breakout board or the power for the buttons and the volume control.

#### Buttons
I also had to restrict the number of input pins used by the buttons, as quite a lot of the digital or analog input pins of the Arduino are already used up.

I connected the 4 control buttons to only one analog input pin (here A1) and used different resistors to distinguish which button is pressed. I took the input power from the +5V line. The buttons output is also tied (via a 10KOhm resistor) to ground to keep it from floating.

The volume control potentiometer is attached to A0 and is also connected to ground via a 10KOhm resistor. It's input voltage is taken from the +5V line.

The programming button is attached to the +3V line and tied to A3 with it's second leg - no ground connection.

#### Low Battery Output
The Adafruit Powerboost 1000c comes with an LBO (Low Battery Output). This usually ties to the battery plus line but ties to ground once the battery reaches a level of roughly 3,4V. So I attached a wire to the LBO pin of the Powerboost and connected it to A2 plus ground (via a 100KOhm resistor)
ATTENTION: This is not yet operational!!!

## Software Design / Operations
The Fairytale program will play albums (audiobooks or music) stored on the SD card inserted into
the Adafruit Music Maker Shield. Selection of the album/audiobook to play is done by
placing corresponding NFC Tags on the NFC Reader.

### Track DB - connect NFC Tag to Audiobook
Upon detection of an NFC Tag, the program will retrieve the tag's UID and use this to scan what I call the TrackDB to find a matching directory to play.

The TrackDB is a list of files in a special directory (SYSTEM00) on the SD card. The TrackDB
files are of the form:

    taguid:directory:track number

e.g.:    

    46722634231761290:findorie:1

In the given example:
- 46722634231761290 is the UID of the NFC Tag
- findorie is the directory from which to play the files
- 1 is the number of the track with which to start playback|

### Playback
The program will take the retrieved information from the TrackDB and then start a for-loop beginning with
the provided first track until all consecutive numbered tracks are played. After playback of all
files is finished, the program will resume it's main loop, delay operation for roughly 15 seconds
(to give the user the chance to remove the just used Tag from the reader) and then wait until
it detects the next tag.

While advancing through the files in the directory, the program will update the TrackDB-File with the
number of the currently played track. Doing so allows for interrupted playbacks - tag is removed and
later put back on when the playback will start with the last track in playback.

### Restrictions
For this to work, a couple of restrictions are in place:
1. All filenames must be in the format  trackXXX.mp3  - where XXX is a numbering from 001 to 127
2. You can have a maximum of 127 files per directory - as I use a char to count the files to preserve memory
3. All directory names must be exactly 8 chars long - use any combination of a-z and 0-9 chars for the name
4. if a file is missing in a consecutive order of files in a directory, you may get a (very short) pause which might result in a glitch in the sound while the next track number is calculated
5. All directories must be directly in the root- directory of the SD card - no sub directories are allowed as I use a char array of 9 chars for the directory part of the path to the file.

### Lights
While the album (or file) is played an operations light is fading up and down in intensity.

On warnings or errors a warning or error light is lit up respectively.

### Errors and Warnings
There are 3 different warning or error conditions:
1. Missing or invalid information for playback warning
2. Low Battery warning
3. Missing or hardware failure error

Additionally we distinct warnings and errors for whether or not we need to turn off the box.

#### Errors
Errors shown via the error light (also cause the system to halt and the Box must be turned off):
- Music Maker Shield not found
- Music Maker shield not on an interrupt enabled pin
- SD card not found
- NFC Reader not found (currently no light effect implemented)

#### Warnings
Warnings shown via a light (Arduino can stay turned on):
- no directory found for the NFC Tag (aka TrackDB is missing an entry for the Tag)
- no directory found on the SD card that match the NFC Tag TrackDB record
- no files in the provided directory
- a missing file in a consecutive list of ordered files in the directory
 this may happen in case the files are not numerically ordered without a gap:
 track001.mp3 exist, track002.mp3 is missing but track003.mp3 exists again

Additionally if the Adafruit Powerboost 1000c detects a low battery level (LBO of the Powerboost ties to ground) the error LED is shown. Surely the Arduino will turn off at some point from now, but until then it will continue to operate.

#### Voice feedback
Additionally to the warning or error lights certain messages are spoken through the music maker shield.
Voiced errors and warnings are:
- Low Battery warning (only voiced if no album is playing)
- No directory found for the NFC Tag (aka TrackDB is missing an entry for the Tag)
- No directory found on the SD card that match the NFC Tag TrackDB record
- No file(s) in the directory on the SD card
- PN532 NFC Reader is malfunctioning.

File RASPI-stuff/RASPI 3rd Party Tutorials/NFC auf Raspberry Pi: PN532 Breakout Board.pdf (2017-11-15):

# NFC auf Raspberry Pi: PN532 Breakout Board

Ich entwickle zurzeit eine kleine Software, welche es ermöglicht, einen interaktiven, verschlüsselten Datenaustausch zwischen einem NFC- (https://www.schnatterente.net/technik/near-field-communication-nfc-rfid)fähigen Android-Smartphone und einem computergesteuerten NFC-Lesegerät durchzuführen.

Um auch zu Hause an dem Projekt arbeiten zu können, habe ich mir ein NFC-Breakout-Board für meinen Raspberry Pi gekauft. In diesem Artikel will ich aufzeigen, wie man das Gerät an die GPIO-Pins des Raspberry Pi anschließt und wie man es konfiguriert.

Alles was man dafür braucht, ist ein Raspberry Pi, (http://de.farnell.com/) ein paar Jumperkabel und ein passendes NFC-Breakout-Board (Details siehe unten).

Zwischenbemerkung: Warum ein PN532-NFC-Breakout-Board?

Falls sich jemand fragt, warum ich mir nicht einfach einen USB-NFC-Reader gekauft habe: Für meinen Anwendungsfall ist es nötig, mit dem NFC-Lesegerät einen NFC-Tag zu emulieren. Dies funktioniert nur mit dem NXP PN532 NFC-Controller problemfrei (die neueren PN533-Chips können das nicht mehr).

Zwar gab es von Identive (früher SCM Microsystems) eine sehr gut funktionierende USB-Version des PN532-Controllers (Arygon ADRB-USB), diese wird aber nicht mehr produziert und ist im Handel auch nicht mehr zu bekommen.

Die PN532-Breakout-Boards bekommt man hingegen sehr einfach. Es gibt verschiedene Ausführungen dieser Platinen. In der Regel steht in der

Beschreibung, dass sie für die Arduino-Plattform gedacht sind. Mit dem Raspberry Pi kann man sie aber genauso benutzen.

(Hinweis für ganz Interessierte: Man kann sich auch ein Breakout-Board kaufen und es an eine USB-UART-Bridge hängen, (http://amzn.to/JFTeeQ) dann hat man einen selbst gebauten USB-NFC-Reader.)

PN532 Breakout Board: Was ich gekauft habe ...

Ich habe mich für diese Ausführung entschieden, (http://amzn.to/1idXFtq) weil hier schon alle Pins auf dem Board angebracht sind. Bei Amazon (http://amzn.to/1ejiIYx) und eBay (http://ebay.eu/KvNZ1s) findet man auch Platinen, bei denen man erst ein bisschen Löten muss, bevor man loslegen kann (die benötigten Stecker und Pins werden oftmals nicht mitgeschickt).

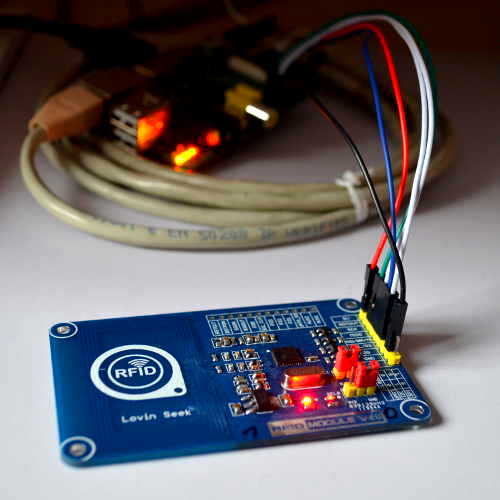
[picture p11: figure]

Zum Lieferumfang gehört auch ein kleiner (Mifare Classic) NFC-Tag mit 1 Kilobyte Speicherkapazität (Schlüsselanhänger-Ausführung).

PN532-Breakout-Board Modi: SPI, UART und I²C

Das RFID/NFC-Shield unterstützt gleich drei Kommunikationsarten: SPI, (http://t1p.de/http://de.wikipedia.org/wiki/Serial_Peripheral_Interface) UART (http://t1p.de/http://de.wikipedia.org/wiki/UART) und I²C. (http://t1p.de/http://de.wikipedia.org/wiki/I2c) Je nachdem, für welche Kommunikationsart man sich entscheidet, verändert sich auch die Verkabelung zwischen dem Breakout-Board und dem Raspberry Pi sowie die Software-Konfiguration (LibNFC).

Ich habe alle drei Varianten getestet und werde sie im Folgenden auch alle erklären. Zuvor möchte ich aber noch (als Entscheidungshilfe) ein paar Worte zu den Geschwindigkeitsunterschieden zwischen UART, I²C und SPI, und auch zu den bei mir aufgetretenen Problemen los werden.

UART (manchem vielleicht eher als serielle Schnittstelle RS232 bekannt):

Recht langsame Verbindung (115,2 kbps).
Für die Verbindung mit dem Raspberry Pi werden vier Jumperkabel (http://amzn.to/1ddFAwi) benötigt.
Wird auch im oben genannten Arygon ADRB-USB-NFC-Reader genutzt (über eine CP2102 USB-UART-Brücke). (http://amzn.to/JFTeeQ) Man müsste also davon ausgehen, dass es gut funktioniert. Bei meinem Breakout-Board ist dies leider nicht zu 100% der Fall. Ich kann via UART zwar problemlos NFC-Tags lesen und schreiben, beim Emulieren eines Tags gibt es aber Timing-Probleme, die zur Fehlfunktion führen.

Ich vermute, dass dieser Fehler bei einer anderen Ausführung des Breakout-Boards nicht auftritt. Wahrscheinlich hat meins nur eine kleine Macke, ich habe dazu jedenfalls nichts im Netz gefunden.

(Noch mal für die ganz Interessierten: Das gleiche Problem habe ich auch, wenn ich das Board über die oben verlinkte UART-Bridge an den USB-Port meines Laptops hänge.)

I²C:

Etwas schnellere Verbindung (400 kbps).

Für die Verbindung mit dem Raspberry Pi werden vier Jumperkabel (http://amzn.to/1ddFAwi) benötigt.
Funktioniert mit meinem PN532-Board eher mäßig, weil die I²C-Verbindung instabil ist. Laut # i2cdetect springt die ID des Boards auf dem I²C-Bus immer zwischen 24 und 25 hin und her. Somit ist keine längere NFC-Verbindung möglich, wie ich sie für meinen Anwendungsfall bräuchte. Dieses Problem scheint es mit vielen NFC-Breakout-Boards zu geben. Im Netz findet man jedenfalls einige englischsprachige Foreneinträge dazu.

SPI:

Sehr schnelle Verbindung (>4 mbps, Full Duplex).
Für die Verbindung mit dem Raspberry Pi werden sechs Jumperkabel (http://amzn.to/1ddFAwi) benötigt.
Läuft perfekt und sehr schnell, sogar schneller als der bereits erwähnte Arygon ADRB-USB-Reader, den ich außer Haus nutze. (Wenn man bedenkt, dass die maximale Geschwindigkeit einer NFC-Funkverbindung bei 106 bis 424 kbps liegt, ist dies auch nicht verwunderlich, denn UART schafft nur 115,2 kbps.)

Damit sollte eigentlich auch klar sein, in welche Richtung meine Empfehlung geht. SPI siegt auf ganzer Linie, braucht aber auch zwei Datenleitungen mehr. Via UART läuft das Breakout-Board ebenfalls nahezu stabil, von I²C würde ich eher die Finger lassen.

Es folgen nun die Beschreibungen zur Einrichtung des RFID/NFC-Boards für die genannten Betriebsmodi. Softwareseitig beziehe ich mich bei diesem Tutorial auf LibNFC, (http://t1p.de/http://nfc-tools.org/index.php?title=Libnfc) die wohl am weitesten ausgereifte Open-Source-Library für NFC und RFID. (Wer lieber Python mag, kann sich mit nfcpy (http://t1p.de/https://launchpad.net/nfcpy) vertraut machen - ich selbst habe das nur kurz angetestet.)

Beim Betriebssystem gehe ich von einer aktuellen Raspbian-Version aus. Hierzu sei noch erwähnt, dass ich mein Breakout-Board erst mit UART und I²C zum Laufen bekam, nachdem ich mein Raspbian-Linux neu aufgesetzt habe. Meine alte Version (vor circa einem Jahr installiert) habe ich zwar immer geupdatet, aber aus irgendeinem Grund wollte sich das System nicht mit der Hardware verstehen. Wer also aus nicht nachvollziehbaren Gründen gar nichts zum Laufen bekommt, sollte sich mal eine zweite SD-Karte nehmen und einen Versuch mit einem neu installierten Linux wagen.

LibNFC installieren

So, jetzt geht's aber wirklich los mit der Installationsanleitung. :)

Zuerst muss LibNFC installiert werden. Mit den folgenden Kommandos wird das Paket heruntergeladen und entpackt:

# wget https://libnfc.googlecode.com/files/libnfc-1.7.0.tar.bz2

# tar -jxvf libnfc-1.7.0.tar.bz2

# cd libnfc-1.7.0

Danach geht es ans Konfigurieren und Kompilieren. Mit dem folgenden Befehl wird LibNFC samt der PN532-Treiber für UART, SPI und I2C konfiguriert. Man kann die --with-drivers-Option auch weglassen, dann werden alle verfügbaren Treiber bereitgestellt. In diesem Fall sollte man LibUSB installiert haben (# apt-get install libusb-dev), da dies für die USB-NFC-Treiber benötigt wird.

Wer sich sicher ist, dass er nur einen bestimmten Treiber braucht, kann die anderen natürlich aus der Zeile entfernen.

./configure --prefix=/usr --sysconfdir=/etc --withdrivers=pn532_uart,pn532_spi,pn532_i2c

Der Befehl # make install all startet die Installation. Der Kompiliervorgang kann auf dem langsamen ARM-Prozessor des Raspberry Pi einige Minuten

dauern.

Die GPIO-Pins des Raspberry Pi: UART, I²C und SPI

Damit man das Breakout-Board an den Raspberry Pi anschließen kann, muss man natürlich erst einmal wissen, welche Pins die richtigen sind. Für alle drei Kommunikationsarten sind GPIO-Pins vorgesehen:

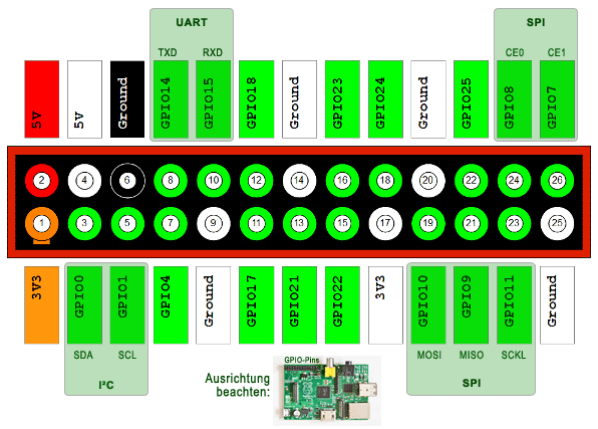
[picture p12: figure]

PN532 Breakout-Board Anschlüsse

Am PN532-Breakout-Board findet man Pins mit den Beschriftungen "3,3V", "5V", "SCK", "MISO", "MOSI/SDA/TX", "SSEL/SCL/RX", "RSTOUT_IN", "IRQ" und "GND". Außerdem sind auf dem Board zwei Jumper (bei manchen Ausführungen auch kleine Schiebeschalter) angebracht, welche zur Auswahl der Kommunikationsart dienen. Ich beschreibe im Folgenden, wie die Jumper auf meinem Board gesetzt werden müssen. Soweit ich es in Bildern gesehen habe, ist dies für alle PN532-Boards in gleicher Weise gelöst. Dennoch empfehle ich jedem, sich nach dem Aufdruck auf seiner Platine zu richten, da es nicht auszuschließen ist, dass sich die Belegung

unterscheidet.

PN532-Breakout-Board via SPI an den Raspberry Pi anschließen

Um das Breakout-Board via SPI mit dem Raspberry Pi zu verbinden, stellt man den Jumper 0 auf "Off" (Jumper sitzt rechts, linker Pin bleibt frei, bei manchen Boards ist die Stellung mit "GND" gelabelt). Jumper 1 muss hingegen auf "On" stehen (manchmal auch mit "3V3" gekennzeichnet).

Für die Verkabelung benötigt man sechs Jumperkabel:

RPi GPIO Pin 2 (5V) ↔ PN532 5V
RPi GPIO Pin 6 (GND) ↔ PN532 GND
RPi GPIO Pin 8 (SPI/CE0) ↔ PN532 SSEL/SCL/RX RPi GPIO Pin 10 (SPI/MOSI) ↔ PN532 MOSI
RPi GPIO Pin 9 (SPI/MISO) ↔ PN532 MISO
RPi GPIO Pin 11 (SPI/SCKL) ↔ PN532 SCK

Software-Konfiguration: PN532 via SPI

Damit SPI auf dem Raspberry Pi verfügbar ist, muss man das zugehörige Kernel-Modul freischalten. Dieses ist in Raspbian standardmäßig über die Blacklist-Datei /etc/modprobe.d/raspi-blacklist.conf gesperrt. Die Zeile mit dem Modul spi-bcm2708 sollte man aus der Datei entfernen oder auskommentieren (ein #-Zeichen davorschreiben). Nach der Änderung muss der Raspberry Pi neu gebootet werden.

Für die Konfiguration von LibNFC folgen unten noch Hinweise.

PN532-Breakout-Board via UART an den Raspberry Pi anschließen

Das Hardware-Setup für UART ist ähnlich simpel, wie das für SPI. Beide Jumper werden auf "Off" (="GND") gestellt. Mit vier Jumperkabeln verbindet man die beiden Platinen:

RPi GPIO Pin 2 (5V) ↔ PN532 5V
RPi GPIO Pin 6 (GND) ↔ PN532 GND
RPi GPIO Pin 14 (TXD) ↔ PN532 SSEL/SCL/RX RPi GPIO Pin 15 (RXD) ↔ PN532 MOSI/SDA/TX

Software-Konfiguration: PN532 via UART

Die Verkabelung wäre also schon mal erledigt. Damit man aber eine UART-Datenverbindung mit dem NFC-Reader herstellen kann, muss man die betreffenden Pins noch softwareseitig freilegen. Denn unter Raspbian sind diese in der Regel schon mit einer Linux-Konsole belegt.

Um diese abzuschalten (und die UART-Pins somit verfügbar zu machen) muss man Folgendes tun:

In der Datei /boot/cmdline.txt entfernt man alle Einträge und Parameter, in denen "ttyAMA0" vorkommt.
Beispiel:
dwc_otg.lpm_enable=0 console=ttyAMA0,115200 kgdboc=ttyAMA0,115200 console=tty1 $
wird zu
dwc_otg.lpm_enable=0 console=tty1 $
In der Datei /etc/inittab kommentiert man die folgende Zeile aus (indem man ein #-Zeichen an den Zeilenanfang schreibt):
# T0:23:respawn:/sbin/getty -L ttyAMA0 115200 vt100

Der Raspberry Pi muss neu gestartet werden.

Weiter unten kommen noch Hinweise zur Konfiguration von LibNFC.

Treib deine Mitmenschen in den Wahnsinn! (https://amzn.to/1gL3MKz)

PN532-Breakout-Board via I²C an den Raspberry Pi

anschließen

Für eine I²C-Verbindung zwischen dem Raspberry Pi und dem PN532-Breakout-Board, setzt man den Jumper 0 auf "On" (="3V3") und Jumper 1 auf "Off" (="GND"). Die Verkabelung erfolgt so:

RPi GPIO Pin 2 (5V) ↔ PN532 5V
RPi GPIO Pin 6 (GND) ↔ PN532 GND
RPi GPIO Pin 0 (SDA) ↔ PN532 MOSI/SDA/TX RPi GPIO Pin 1 (SCL) ↔ PN532 SSEL/SCL/RX

Software-Konfiguration: PN532 via I²C

Auch für I²C wird ein gesperrtes Kernel-Modul benötigt. Dieses heißt i2cbcm2708 und ist ebenfalls in der Datei /etc/modprobe.d/raspi-blacklist.conf geblacklisted. Der Eintrag muss auskommentiert (ein #-Zeichen davorschreiben) oder entfernt werden.

Des Weiteren sollte man das Modul i2c-dev explizit zur Datei /etc/modules hinzufügen (einfach "i2c-dev" in eine neue Zeile schreiben).

Außerdem empfiehlt es sich, die i2c-Tools zu installieren (# apt-get install i2c-tools). Damit verfügt man auch über das Programm i2cdetect, mit welchem man überprüfen kann, ob der NFC/RFID-Reader gefunden wurde. Hierzu gibt man als root-Nutzer # i2cdetect -y 1 ein (bei älteren Rasperry Pi Revisionen muss der Befehl # i2cdetect -y 0 lauten).

Der Output sieht dann ungefähr so aus:

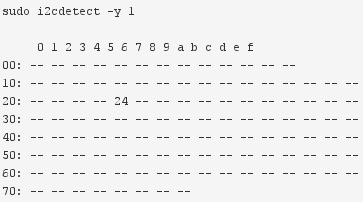
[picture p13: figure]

In diesem Fall meldet sich das Board mit der ID 24 auf dem I²C-Bus zu Wort. Wie oben schon erwähnt, springt der Wert bei mir des Öfteren zwischen 24 und 25 hin und her, weswegen ich I²C nicht benutze.

Es folgt der letzte Schritt der Konfiguration: die LibNFC-Einrichtung.

LibNFC Konfiguration

LibNFC benötigt noch zwei Konfigurationsdateien, damit es den NFC/RFID-Reader auch findet. Für diese legt man im /etc/-Verzeichnis die Ordner nfc und nfc/devices.d an.

Die Datei /etc/nfc/libnfc.conf enthält nur eine Zeile.

allow_intrusive_scan=true

Wichtiger ist die Datei /etc/nfc/devices.d/device.conf, welche für SPI den folgenden Inhalt aufweist:

name = "Breakout Board"
connstring = pn532_spi:/dev/spidev0.0:500000

Für UART lautet der Connstring wie folgt:

name = "Breakout Board"
connstring = pn532_uart:/dev/ttyAMA0

Bei I²C ist der Connstring, wie oben schon angedeutet, von der Geräte-Version abhängig. Er lautet

name = "Breakout Board"
connstring = pn532_i2c:/dev/i2c-0

oder

name = "Breakout Board"
connstring = pn532_i2c:/dev/i2c-1

Damit wäre die Konfiguration beendet und das Breakout-Board sollte sich mit LibNFC verwenden lassen. Zum Testen kann man einfach mal den Befehl # nfc-list eingeben. Für SPI sieht der Output dann so aus:

# nfc-list

nfc-list uses libnfc 1.7.0
NFC device: pn532_spi:/dev/spidev0.0 opened

(Wenn ein Tag auf dem Reader liegt, steht noch ein bisschen mehr da.)

Mehr zur LibNFC-Konfiguration findet man hier. (http://t1p.de/http://nfc-tools.org/index.php?title=Libnfc:configuration) Bei Problemen kann man vor jeden LibNFC-Befehl "LIBNFC_LOG_LEVEL=3" schreiben, dann bekommt man ausführlichere Debug-Informationen angezeigt.

Damit wäre ich auch am Ende dieses Artikels angelangt. Ich hoffe das Tutorial hilft jemandem bei der Konfiguration seines NFC/RFID-Readers weiter.

Mehr Artikel zum Thema NFC, gibt es hier. (http://www.schnatterente.net/tag/NFC)
Bei Fragen, einfach kommentieren. :)

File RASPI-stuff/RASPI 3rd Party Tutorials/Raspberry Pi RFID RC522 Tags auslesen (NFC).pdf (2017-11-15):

# Raspberry Pi RFID RC522 Tags auslesen (NFC)

Felix (https://tutorials-raspberrypi.de/author/felix/) Mai 06, 2016

RFID ist eine Technologie, wodurch Daten ohne Berührung übertragen werden, was in Chipkarten Anwendung findet. Mit einem Raspberry Pi RFID Modul (RC522) können Zugangskarten ausgelesen werden und somit z.B. Zugriff zu Türen oder Schlössern gegeben werden. Aktuelle Smartphones besitzen ähnliche

Wie man mit dem RC522 und dem Raspberry Pi RFID Tags ausließt und außerdem Chipkarten beschreibt, zeige ich in diesem Tutorial. Außerdem kann der vorgestellte Code für andere Projekte (Türöffner, Zugangskontrolle) verwendet werden.

NFC ist eine zugehörige Technologie, dessen Unterschiede hier (http://blog.atlasrfidstore.com/rfid-vs-nfc) nachgelesen werden können (Englisch). Sowohl RFID als auch NFC senden auf einer Frequenz von 13.56 MHz, weshalb die Module miteinander kompatibel sind.

Verwendetes Zubehör

Die folgenden (Bau-)Teile habe ich für dieses Tutorial verwendet:

Raspberry Pi 3 (http://www.amazon.de/gp/product/B01CEFWQFA?camp=1634&creative=6738&creativeASIN=B01CEFWQFA) (funktioniert auch mit allen Vorgängern) Mifare RC522 RFID Modul (http://www.amazon.de/gp/product/B00QFDRPZY?camp=1634&creative=6738&creativeASIN=B00QFDRPZY) (inkl. KeyCard)
Female – Female Jumper Kabel (https://rover.ebay.com/rover/1/707-53477-19255-0/1?toolid=20001&campid=5338064322&customid=link)
Lötutensilien

Es gibt auch RFID USB Lesegeräte, (http://www.amazon.de/mn/search/?camp=1634&creative=19450&field-keywords=RFID%20USB%20Leseger%C3%A4t) allerdings habe ich diese nicht ausprobiert.

Falls man das Kartenlesegerät als Eingangskontrolle, etc. verwenden will, macht es Sinn jedem Nutzer eine Karte zu geben. Man kann diese Chipkarten in kleineren und größeren Mengen auch für kleines Geld zusätzlich erwerben (http://www.amazon.de/mn/search/?camp=1634&creative=19450&field-keywords=RFID%20Karten) und dann mit dem RC522 jede Karte individuell beschreiben (Anleitung dazu weiter unten).

Aufbau

Bei meinem Modul war die Pin Leiste noch nicht angelötet, daher musste ich sie erst löten, bevor ich die Pins verbinden konnte.
Die Verkabelung ist dabei wie folgt:
RF522 Modul | Raspberry Pi
SDA | Pin 24 / GPIO8 (CE0)
SCK | Pin 23 / GPIO11 (SCKL)
MOSI | Pin 19 / GPIO10 (MOSI)
MISO | Pin 21 / GPIO9 (MISO)
IRQ | —
GND | Pin6 (GND)
RST | Pin22 / GPIO25
3.3V | Pin 1 (3V3)

Schematisch sieht das ganze dann so aus:

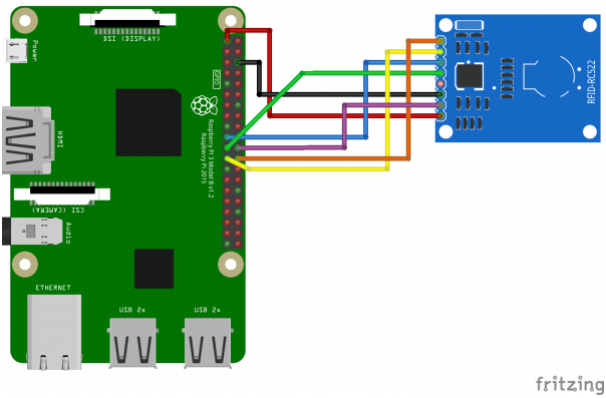
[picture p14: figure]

Raspberry Pi RC522 Verbindung

SPI aktivieren und Software installieren

Um das RFID RC522 Shield verwenden zu können brauchen wir den SPI Bus. Damit der Kernel beim Starten geladen wird, bearbeiten wir die config Datei:

sudo nano /boot/config.txt

Folgender Inhalt wird an das Ende der Datei hinzugefügt:

device_tree_param=spi=on
dtoverlay=spi-bcm2708

Gespeichert und beendet wird mit STRG+O, STRG+X. Danach aktivieren wir SPI noch:

sudo raspi-config

Unter „Advanced Options“ > „SPI“ aktivieren und den Neustart bestätigen (alternativ sudo reboot now).

Danach kann mittels dmesg | grep spi überprüft werden, ob das Modul
geladen wurde. Es sollte dann so einen Output ergeben:

Nun müssen noch die Pakete installiert werden, sodass wir auf den SPI Bus zugreifen können und eine entsprechende Bibliothek aus GitHub (https://github.com/mxgxw/MFRC522-python.git) laden können.

sudo apt-get install git python-dev --yes pi@raspberrypi:~ $ dmesg | grep spi
[ | 10.784368] bcm2708_spi 20204000.spi: master is unqueued, this is deprecated
[ | 10.813403] bcm2708_spi 20204000.spi: SPI Controller at 0x20204000 (irq 80)

Zu erst installieren wir also das Python SPI Modul

git clone https://github.com/lthiery/SPI-Py.git cd SPI-Py
sudo python setup.py install
cd ..

und danach die Raspberry Pi RFID RC522 Bibliothek:

git clone https://github.com/mxgxw/MFRC522-python.git && cd MFRC522-python

Raspberry Pi RFID Reader/Writer testen

Zusätzlich zum RC522 Modul werden meist eine weiße Karte sowie ein NFC fähiger Schlüsselanhänger geliefert. Diese Teile können als Authentifizierung benutzt werden, da sie beschreibbar und lesbar sind. Ebenfalls könnte ein NFC fähiges (Android/iOS) Smartphone verwendet werden (was die meisten neueren Handys ja sind).

Um einen ersten Test der Karte/Schlüsselanhängers durchzuführen, lassen wir das Skript laufen:

sudo python Read.py

Sobald die Chipkarte daran gehalten wird und erkannt wird, sieht man eine Ausgabe wie diese:

pi@raspberrypi:~/MFRC522-python $ sudo python Read.py Welcome to the MFRC522 data read example
Press Ctrl-C to stop.
Card detected
Card read UID: 69,245,238,117
Size: 8
Sector 8 [0, 0, 0, 0, 0, 0, 0, 0, 0, 0, 0, 0, 0, 0, 0, 0]

Um nun die gespeicherten Daten (Zahlen) auf dem Chip zu ändern, bearbeiten wir die „Write.py“ Datei (sudo nano Write.py). Dazu bearbeitest du den Code ab Zeile 55 folgendermaßen (die 16 Zahlen von data kannst du dabei frei zwischen 0 und 255 wählen. Ich habe dabei ein Wort mit ASCII Zeichen dargestellt): (http://asciivalue.com/index.php)

# Variable for the data to write

data = [114, 97, 115, 112, 98, 101, 114, 114, 121, 45, 116, 117, 116, 111, 114, 0]

# Fill the data with 0xFF

#for x in range(0,16):

# data.append(0xFF)

print "Sector 8 looked like this:"

# Read block 8

MIFAREReader.MFRC522_Read(8)

print "\n"

#print "Sector 8 will now be filled with 0xFF:"

# Write the data

MIFAREReader.MFRC522_Write(8, data)

#print "\n"

print "It now looks like this:"

# Check to see if it was written

MIFAREReader.MFRC522_Read(8)

print "\n"

"""

data = []

# Fill the data with 0x00

for x in range(0,16):

data.append(0x00)

print "Now we fill it with 0x00:"

MIFAREReader.MFRC522_Write(8, data)

print "\n"

print "It is now empty:"

# Check to see if it was written

MIFAREReader.MFRC522_Read(8)

print "\n"

"""

NFC / RFID Reader in Raspberry Pi Projekten verwenden (Türschloss, etc.)

Die beiden Python Dateien „Read.py“ und „Write.py“ enthalten einigen Beispielcode zum Lesen und beschreiben eines Chips, der in anderen Projekten zum Einsatz kommen kann. Die wichtigste Datei ist dabei „MFRC522.py“, welche in ein anderes Projekt mit kopiert werden kann.

Der folgende Ausschnitt kann in anderen Projekten verwendet werden, wie z.B. als Überprüfung eines Codeschloss bzw. Türschloss. Ich verwende eine Authentifizierungsstufe (man könnte auch mehrere einstellen) mit einem bestimmten Anfangs-Code. Die letzten Ziffern geben Auskunft über den Inhaber der Karte (sofern irgendwo dazu Daten gespeichert sind). Man könnte den User auch nur anhand der UID identifizieren, allerdings gehe ich vom Fall aus, dass auch mehrere Karten einem Nutzer gehören können.

Wem diese Lösung nicht gefällt, kann es natürlich umändern.

Ich habe in der Datei „MFRC522.py“ eine kleine Änderung vorgenommen, sodass die Funktion MIFAREReader.MFRC522_Read einen Rückgabewert hat:

def MFRC522_Read(self, blockAddr):

recvData = []

recvData.append(self.PICC_READ)

recvData.append(blockAddr)

pOut = self.CalulateCRC(recvData)

recvData.append(pOut[0])

recvData.append(pOut[1])

(status, backData, backLen) = self.MFRC522_ToCard(self.PCD_TRANSCEIVE, recvData)

if not(status == self.MI_OK):

print "Error while reading!"

i = 0

#if len(backData) == 16:

# print "Sector "+str(blockAddr)+" "+str(backData)

return backData

Der Beispielcode sieht dann folgendermaßen aus (die vorherigen Änderungen sind wichtig, da sonst kein Vergleich stattfinden kann):

#!/usr/bin/env python

# -*- coding: utf8 -*-

import RPi.GPIO as GPIO

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
import MFRC522

def sample_func(sample_var):

# Beispiel Funktion

# Skript starten, Daten loggen, etc.

print("Test Funktion wurde aufgerufen")

MIFAREReader = MFRC522.MFRC522()

authcode = [114, 97, 115, 112, 98, 101, 114, 114, 121] # die ersten 9 Ziffern sind der Authentifizierungscode

try:

while True:

# Scan for cards

(status,TagType) =
MIFAREReader.MFRC522_Request(MIFAREReader.PICC_REQIDL)

# If a card is found

if status == MIFAREReader.MI_OK:

# Get the UID of the card

(status,uid) = MIFAREReader.MFRC522_Anticoll()

# This is the default key for authentication

key = [0xFF,0xFF,0xFF,0xFF,0xFF,0xFF]

# Select the scanned tag

MIFAREReader.MFRC522_SelectTag(uid)

# Authenticate

status =
MIFAREReader.MFRC522_Auth(MIFAREReader.PICC_AUTHENT1A, 8, key, uid)

# Check if authenticated

if status == MIFAREReader.MI_OK:

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
# Read block 8

data = MIFAREReader.MFRC522_Read(8)

if data[:9] == authcode:

sample_func(data)

#elif ...

except KeyboardInterrupt:

print("Abbruch")

GPIO.cleanup()

Wie man sieht ist der Code sehr simpel und soll, wie gesagt, nur als Anstoß dienen um eigene ausgefeiltere Anwendungen damit zu starten. Der Code in Zeile ist natürlich anzupassen

Welche Projekte setzt ihr damit um? Ich überlege ein Türschloss bzw. ein Schubladenschloss/kleinen Tresor mit dem Raspberry Pi RFID Reader zu bauen.

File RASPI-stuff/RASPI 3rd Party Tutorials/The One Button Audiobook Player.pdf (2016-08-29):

## The One Button Audiobook Player

This little Raspberry Pi based project is a gift for my wife’s grandmother for her 90th birthday. Being visually impaired, she is hard to entertain but loves to listen to audiobooks. The problem is, that she isn’t able to handle a ghetto blaster or MP3 player.
The solution to this problem was – tadaaaah – a one button audiobook player
It basically consists of:
1 Raspberry Pi
1 ModMyPi enclosure (https://www.modmypi.com/)
1 button
2 resistors (330 Ohm, 10 Kilo-Ohm) 1 blue LED
1 (slow) 8GB SD-Card
some wire
a pair of speakers
The following software has been used:
Raspbian minimal image (http://www.linuxsystems.it/2012/06/raspbian-wheezy-armhf-raspberry-pi-minimal-image) (http://www.linuxsystems.it/2012/06/raspbian-wheezy-armhf-raspberry-pi-minimal-image/)
mpd (music player daemon)
mpc
mpd-python
pyudev (for USB access)
a self-written python script
The features are the following:
always on: When you power on the raspberry, it will boot up and start the python script with the audio book in pause
one button usage: The button pauses and unpauses the audio book or goes back one track when you press the button longer than 4 seconds
remembers position: It will always remember the last played position
only one audiobook: There will always be only one audio book on the Raspberry easy audio book deployment: When you plug in a USB thumb drive with a special name/label, the Raspberry will stop playing, mount the thumb drive, deletes the old audio book, copies the new one, rebuilds the playlist and – after unplugging the thumb drive – starts the new audiobook in pause mode multi format: Since it uses mpd, the player supports Ogg Vorbis, FLAC, OggFLAC, MP2, MP3, MP4/AAC, MOD, Musepack and wave
Some pics and a video:

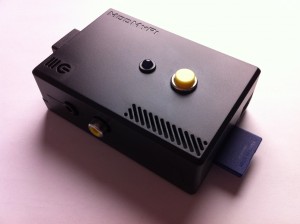
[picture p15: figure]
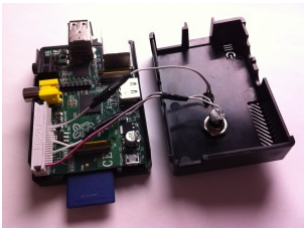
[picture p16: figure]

(The audiobook used in this video is a free version of Cory Doctorows “Little Brother”

from Fabian Neidhardt) (http://www.mokita.de/)
If you like to build your own one button audio book player, here are the super simple schematics:

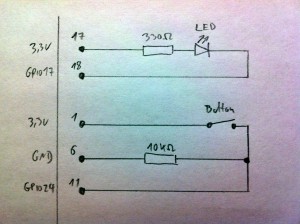
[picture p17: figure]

And last but not least – the python script. The code might be crappy, please comment if you have improvements (especially regarding loadMusic). You can find it on github: https://github.com/exitnode/theonebuttonaudiobookplayer
Update (2013-11-26)
Here’s what Russel wrote in a comment to this post:
“I just completed building this and have some addendum notes adding more details: Install the following packages:
sudo apt-get install mpd
sudo apt-get install mpc
sudo apt-get install python-mpd
sudo apt-get install python-pyudev
(below assumes using defaults for /etc/mpd.conf) sudo mkdir -p /music/usb
sudo ln -s /var/lib/mpd /music/mpd
sudo ln -s /var/lib/mpd/music /music/mp3
Copy the tobabp.py script to /home/pi
nano /home/pi/tobabp.py
Change these in the script or flip the connections in wiring diagram. BUTTON = 17
LED = 24
Testing

Rename a USB stick to “1GB” Copy 1 MP3 onto the stick
Insert the stick into pi
sudo mount /dev/sda1 /music/usb sudo /etc/init.d/mpd stop
sudo rm /music/mp3/*
sudo cp /music/usb/* /music/mp3/ sudo umount /music/usb
Remove the USB stick
sudo rm /music/mpd/tag_cache sudo /etc/init.d/mpd start
mpc clear
mpc ls
mpc ls | mpc add
sudo /etc/init.d/mpd restart mpc play
Plug in earphones
You should hear audio
Next try the python script:
sudo python /home/pi/tobabp.py
Insert USB stick
the LED should flash and the USB file copy to /music/mp3/
the LED should flash again. Remove the Stick and LED flashes again. Press button to start playing
Press button again to stop
Press & hold button to rewind to beginning.
sudo crontab -e
Add following line run at startup
@reboot python /home/pi/tobabp.py & sudo reboot
Then retest again to be sure all is well.”

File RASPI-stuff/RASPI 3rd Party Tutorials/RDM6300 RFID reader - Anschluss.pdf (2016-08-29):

## Raspberry Pi: RDM6300 RFID reader

I mentioned in this post (http://chris-labs.de/electronics/raspberrypi/2013/09/17/raspberrypi-first-time-setup.html) that the RDM6300 can be connected to the Raspberry Pi. Since then I got several emails from people asking me how to do it. Unfortunately I don’t have my RFID tags anymore. However I made notes when trying to do this the first time. If you encounter any problems / bugs when following these instructions please email me or leave a comment, so we can sort things out. (Update: My thanks to Matthias who tested these instructions and gave some clues to correct them.)
Wiring

Wire it up according to the schematics (click to enlarge). GPIO15 is the UART RX pin of the RPi.

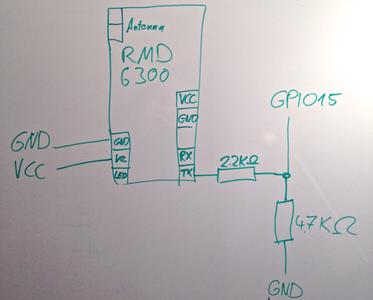
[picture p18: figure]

Software

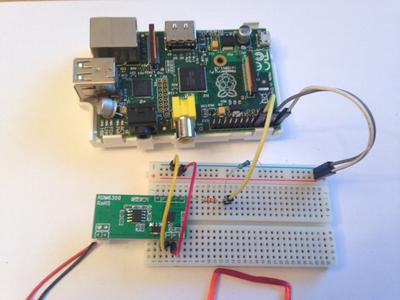
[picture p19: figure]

First disable the kernel debugging UART using sudo raspi-config (it should be under “8 Advanced Options” -> “A8 Serial”). Then install python and the serial package:

sudo apt-get install python python-pip
sudo pip install pyserial

Once you have python setup, create a file readRFID.py with the following content and

execute python readRFID.py.

import serial
import sys
import time
from operator import xor
# UART

ID = ""
Zeichen = 0
Checksumme = 0
Tag = 0
# Flags

Startflag = "\x02"
Endflag = "\x03"
# Open UART (close first just to make sure) UART = serial.Serial("/dev/ttyAMA0", 9600) UART.close()

UART.open()
while True:
# Reset vars

Checksumme = 0
Checksumme_Tag = 0
ID = ""
# Read chars

Again, since I did this a long time ago and reconstructed this post from my notes I can’t guarantee that it works. However Matthias (a reader of this blog) gave me some feedback to correct this tutorial and tested if it works. Thank you for contributing.

Tags: RaspberryPi, (http://chris-labs.de/tag/RaspberryPi.html) RDM6300, (http://chris-labs.de/tag/RDM6300.html) RFID (http://chris-labs.de/tag/RFID.html)
comments powered by Disqus (http://disqus.com/)

Zeichen = UART.read()
# Start of transmission signaled? if Zeichen == Startflag:

# Build ID

for Counter in range(13):
Zeichen = UART.read()
ID = ID + str(Zeichen)
# Remove endflag from string ID = ID.replace(Endflag, "" )

# Calc checksum

for I in range(0, 9, 2):
Checksumme = Checksumme ^ (((int(ID[I], 16)) << 4) + int(ID[I+1], 16)) Checksumme = hex(Checksumme)
# Find tag

Tag = ((int(ID[1], 16)) << 8) + ((int(ID[2], 16)) << 4) + ((int(ID[3], 16)) << 0) Tag = hex(Tag)
# Print data

print "------------------------------------------"
print "Data: ", ID
print "Tag: ", Tag
print "ID: ", ID[4:10], " - ", int(ID[4:10], 16) print "Checksum: ", Checksumme
print "------------------------------------------"

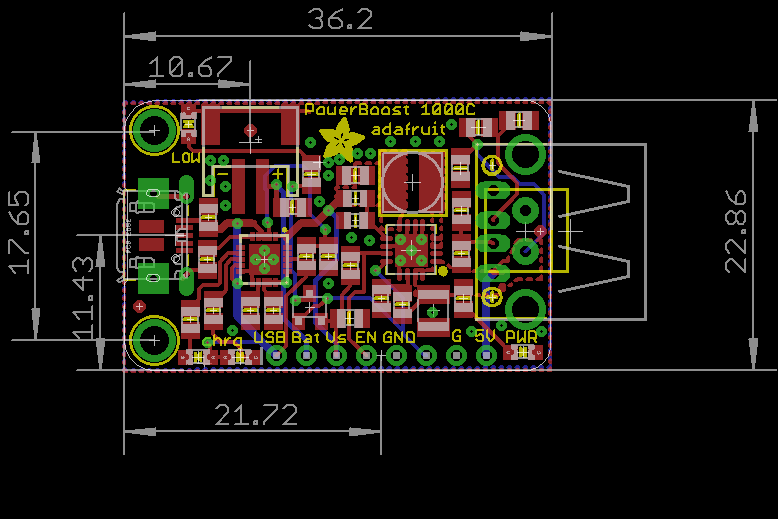
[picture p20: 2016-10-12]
3rd Party Schematics/Adafruit Powerboost 1000c - printout diagram.png

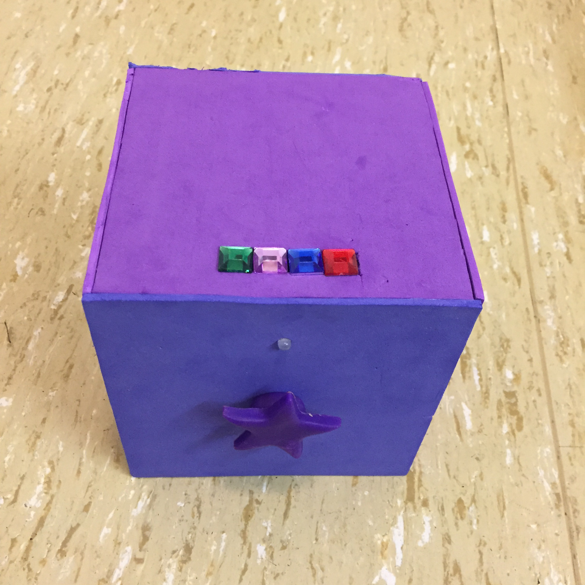
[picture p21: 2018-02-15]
Building Pictures/Top with 4 Buttons Volume and Operations Light.jpg

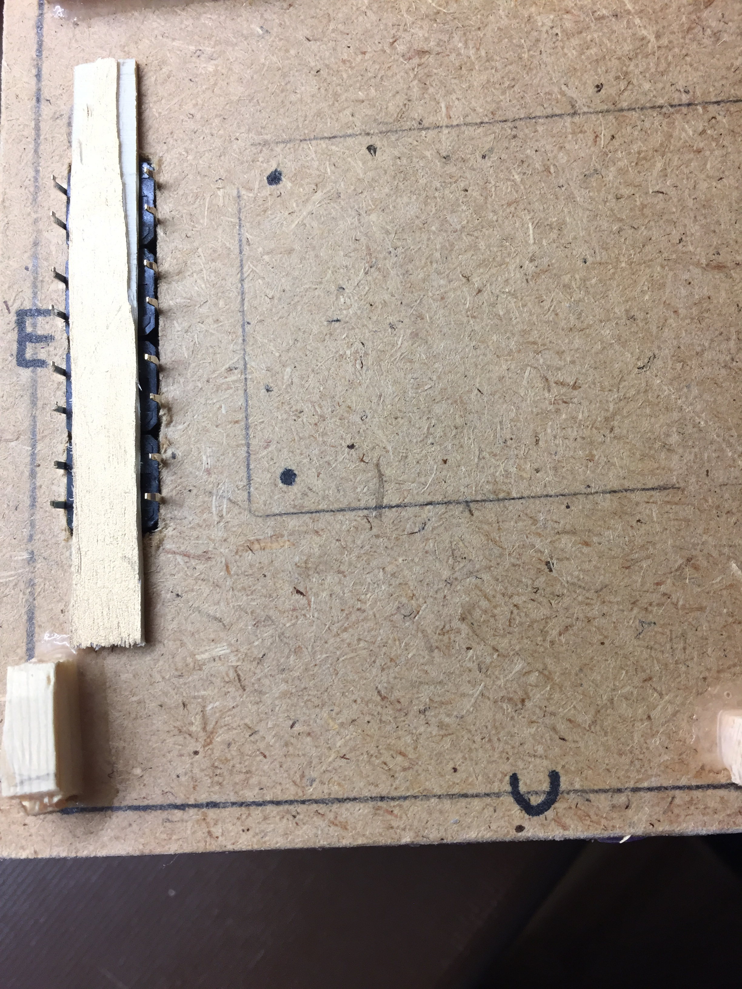
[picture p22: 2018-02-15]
Building Pictures/Top plate back with 4 buttons.jpg

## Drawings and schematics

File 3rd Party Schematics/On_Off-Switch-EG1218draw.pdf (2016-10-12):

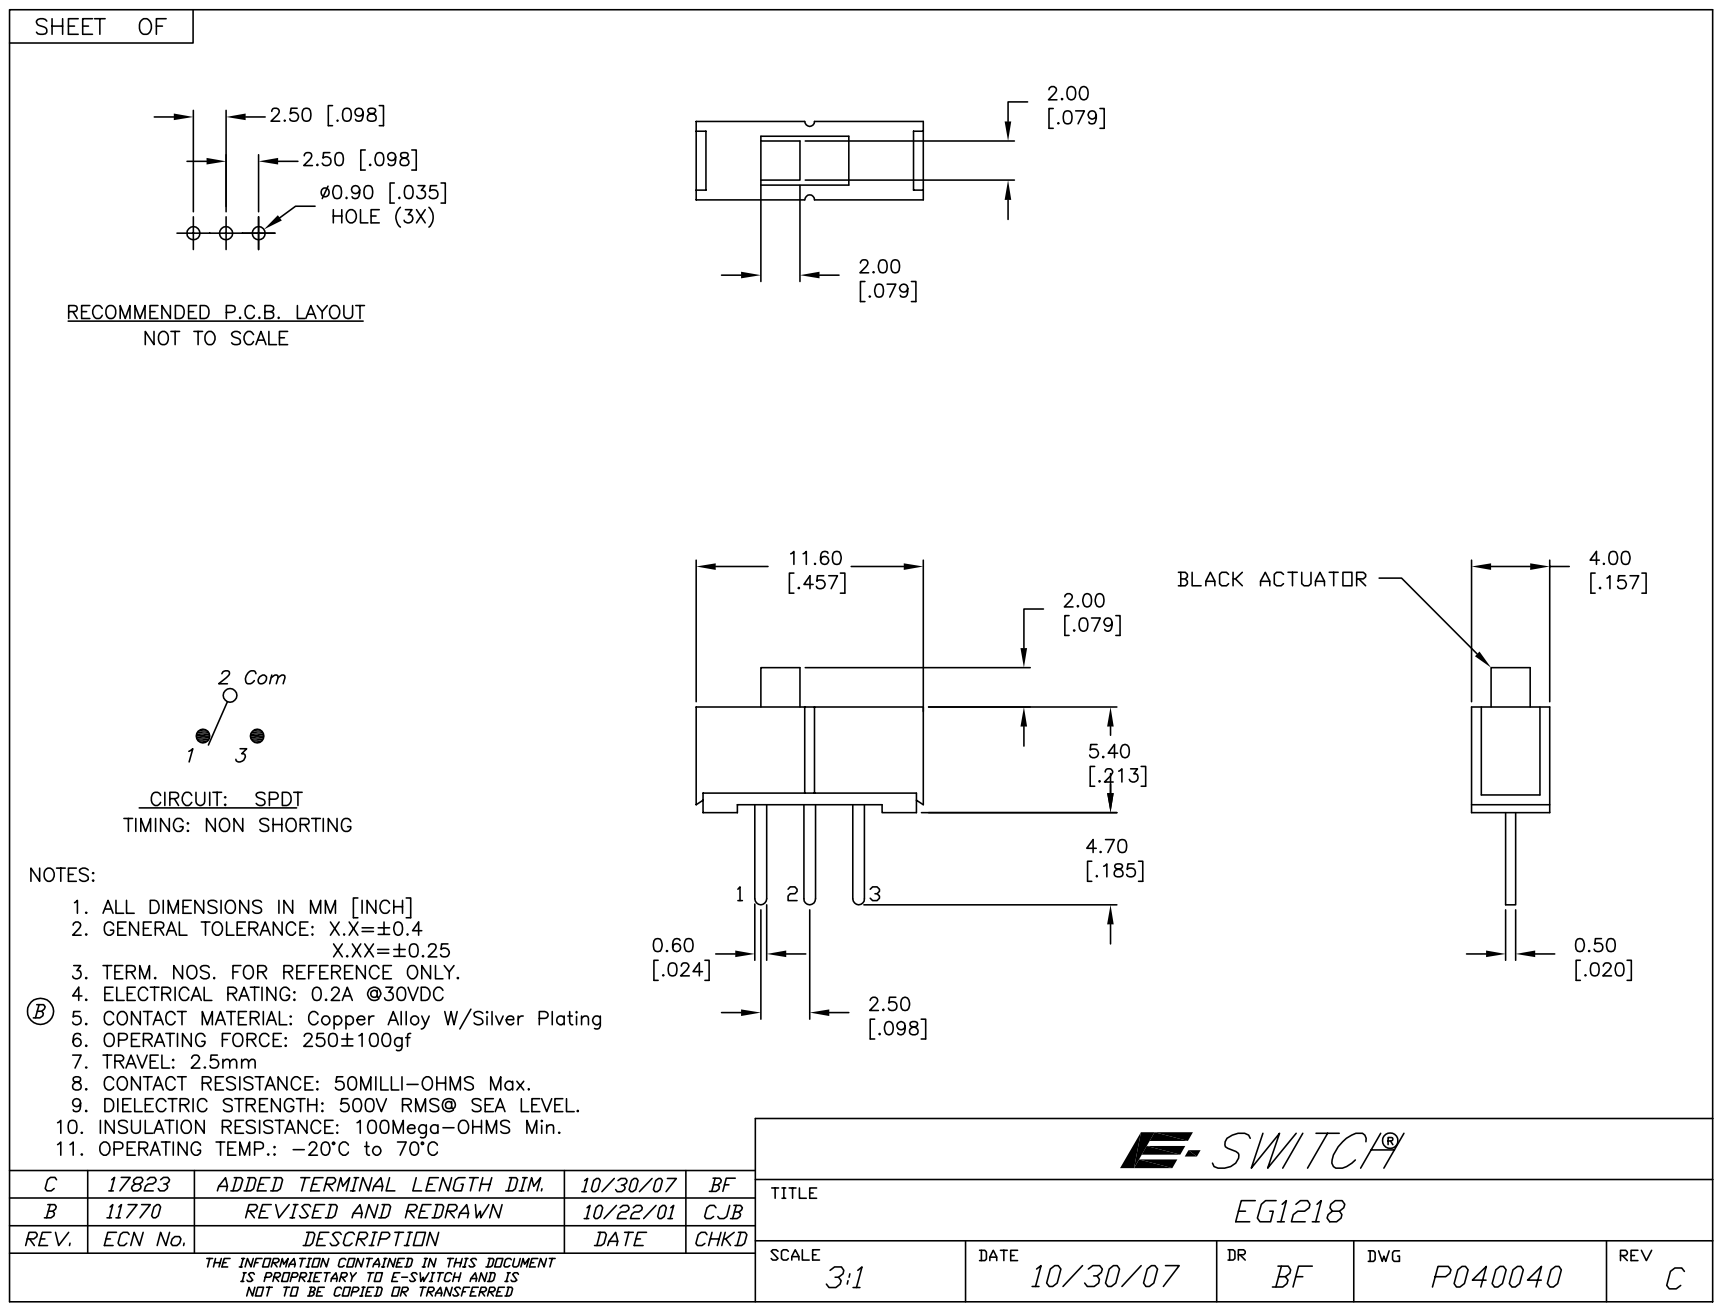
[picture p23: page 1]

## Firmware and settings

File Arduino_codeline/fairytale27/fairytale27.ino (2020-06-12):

#define VERSION 27

// BOF preprocessor bug prevent - insert me on top of your arduino-code
#if 1
__asm volatile ("nop");
#endif

// set according to the baudrate of your serial console. used for debugging output
#define BAUDRATE 115200

/*
   Fairytale Main program
   ---------------------------------------------------------------------------------------
   This programm will play albums (audiobooks or music) stored on the SD card inserted into
   the Adafruit Music Maker Shield. Selection of the album/audiobook to play is done by 
   placing corresponding NFC Tags on the NFC Reader.

   There are two pissibilities on how the connection between an NFC Tag and the corresponding 
   album on the SD card can be setup:
   1. An NDEF Message written to the tag in the form of:  en [directory name]
   2. Via the so called TrackDB - txt-files for each album in the directory trackdb0

   
   NDEF Implementation
   ---------------------------------------------------------------------------------------
   This implementation is based on the Speedmaster PN532 and Don's NDEF Library. Upon 
   detection of an NFC Tag placed on the reader it will check if there is at least one 
   NDEF Message written to the RFID tag. This message must be of the form 

      en [directory name]

   for example, the audiobook "Finding Nemo", stored in files in the directory
   
      /findnemo
      
   would have an NDEF message on the tag which reads as

      en findnemo
   
   There may also be a second NDEF message for the track to start playback with and this 
   would be in the form of

      en 1

   for the first track. To use this implementation you have to activate the configuration 
   option     NFCNDEF     below. For each album you have to write the NDEF Messages with the 
   directory name on the corrresponding tag. 
   This can be done with the program staticNFCWriter.ino from this repository.
   
   There is a downside to this implementation. It lacks a usable update of the track to 
   start playback with - I simply could not get it to work. Secondly the implementation
   lacks a reliable way of detecting the absence of a tag. Therefore the playback can only be 
   stopped by turning the box off. The third problem is with the used progmem. The two libraries 
   consume way too much progmem as opposed to the Adafruit PN532 library therefore I switched to:
   
   
   TrackDB-Implementation:
   ---------------------------------------------------------------------------------------
   Upon detection of an NFC Tag, the program will retrieve the tag's UID and use this to scan 
   what I call the TrackDB to find a matching directory to play.
   
   The TrackDB is a list of files in a special directory (TRACKDB0) on the SD card. The TrackDB
   files are named after the directory of the album and their respective content is of the form:
   
      taguid:directory:track
   
   For example, the audiobook "Finding Dorie" is stored in the directory    
   
      /findorie
      
   on the SD Card. The corresponding TrackDB file is stored at
      
      /trackdb0/findorie.txt

   It contains exactly one line:

      46722634231761290:findorie:1

   This line connects the Tag UID with the aformentioned directory plus the number of the track
   with which to start playback:
   
      46722634231761290   the UID of the NFC Tag
      findorie            the directory from which to play the files
      1                   the number of the track with which to start playback - here the 1st 

   To use this implementation you need to activate the configuration   NFCTRACKDB   
   You will also need to create the necessary TrackDb files. This can be done with the program
   createTrackDb.ino from this repository.
   
   
   Playback and controls
   ---------------------------------------------------------------------------------------
   Regardless of the way the program retrieved the information on which directory to play 
   (NDEF message or TrackDB), it will store this in the global var plrCurrentFolder and then 
   start a for-loop beginning with the provided first track until all consecutive numbered 
   tracks are played - for this it counts the number of files in the given dierctory. 
   
   While the album (or file) is played an operations light is fading up and down in intensity. 
   
   After playback of all files is finished, the program will resume it's main loop, delay 
   operation for roughly 15 seconds (to give the user the chance to remove the just used Tag 
   from the reader) and then wait until it detects the next tag.
   In case the figure is not removed from the reader, the album will be played again. To 
   prevent this from happening, there is a compile time switch below DISABLE_LOOPING. Enabling 
   this switch prevents the box from playing the same album again and again.
   
   While advancing through the files in the directory, the program will update the TrackDB-File 
   with  the number of the currently played track. Doing so allows for interrupted playbacks - 
   tag is removed and later put back on when the playback will start with the last track in 
   playback. <-- Attention this only works with the TrackDB and not with NDEF implementation.
   
   
   Restrictions
   ---------------------------------------------------------------------------------------
   For this to work, a couple of restrictions are in place:
   1. All filenames must be in the format  trackXXX.mp3, where XXX is a numbering from 001 to 127
   2. Follows from 1: You can have a maximum of 127 files per directory. I use a char to count the
      files in a directory to preserve memory and need the ability to return -1 in case of an error
   3. All directory names must be exactly 8 chars long. You may use any combination of a-z 
      and 0-9 chars for the directory name though
   4. if a file is missing in a consecutive order, you may get a glitch in the sound 
   5. As the Adafruit Music Maker Shield library does not support to jump to a specific 
      position within a file, the box can always only start from the beginning of a track.
   
   
   Warnings and errors
   ---------------------------------------------------------------------------------------
   On warnings or errors a warning or error light is lit up respectively. There are 3 
   different warning or error conditions:
   1) Missing information for playback warning
   2) Low Battery warning
   3) Missing hardware error
   
   Errors shown via the error light (also cause the system to halt):
   - Music Maker Shield not found
   - Music Maker shield not on an interrupt enabled pin
   - SD card not found
   - NFC Reader not found

   Warnings shown via a light (Arduino can stay turned on):
   - Low battery warning (surely the arduino will turn off but until then it will operate)
   - no directory found for the NFC Tag (aka TrackDB is missing an entry for the Tag)
   - no directory found on the SD card that match the NFC Tag TrackDB record
   - no files in the provided directory
   - a missing file in a consecutive list of ordered files in the directory
     this may happen in case the files are not numerically ordered without a gap: 
     track001.mp3 exist, track002.mp3 is missing but track003.mp3 exists again

   Additionally to the warning or error lights certain messages are spoken through the music . 
   maker shield. Voiced errors and warnings are:
   - Low Battery warning
   - no directory found for the NFC Tag (aka TrackDB is missing an entry for the Tag)
   - no directory found on the SD card that match the NFC Tag TrackDB record
   - no file(s) in the directory on the SD card


   Controls
   ---------------------------------------------------------------------------------------
   4 buttons are included:
   - Previous Track       - play the previous track in a consecurtive list of ordered files
   - Next Track           - play the next track in a consecurtive list of ordered files
   - Pause / Resume       - pauses the playback or unpauses a paused playback
   - Light on / off       - turn the operations light fader on or off

   
   The box is capable of being controlled by a remote control with the following functions
   - Volume Up            - increase volume by 5 per click
   - Volume Down          - decrease volume by 5 per click
   - Previous Track       - play the previous track in a consecurtive list of ordered files
   - Next Track           - play the next track in a consecurtive list of ordered files
   - Pause / Resume       - pauses the playback or unpauses a paused playback
   - Light on / off       - turn the operations light fader on or off
   
    
   Used Pins:
   ---------------------------------------------------------------------------------------
     NAME             PIN  USAGE
   - CLK / PN532_SCK   13  SPI Clock shared with VS1053, SD card and NFC breakout board 
   - MISO / PN532_MISO 12  Input data from VS1053, SD card and NFC breakout board 
   - MOSI / PN532_MOSI 11  Output data to VS1053, SD card and NFC breakout board 
   
   - SHIELD_CS          7  VS1053 chip select pin (output)
   - SHIELD_DCS         6  VS1053 Data/command select pin (output)
   - DREQ               3  VS1053 Data request, ideally an Interrupt pin
    
   - CARDCS             4  SD Card chip select pin
    
   - PN532_SS          10  NFC breakout board chip select pin

   YOU CAN EITHER CONNECT AND USE THE INFO AND WARNING LEDS OR THE 8x8 LED MATRIX
   - OPRLEDPIN          5  the pin to which the operation led is connected to
   - WRNLEDPIN          8  the pin to which the warning led is connected to
   - ERRLEDPIN          9  the pin to which the error led is connected to 
                            e.g. used for LBO of powerboost 1000c
    
   - MATRIX_DIN         9  the pin for the DATA IN port of the 8x8 led matrix 
   - MATRIX_CS          8  the pin for the Chip Select port of the 8x8 led matrix
   - MATRIX_CLK         5  the pin of the clock cycle port of the 8x8 led matrix
   
   - VOLPOTPIN         A0  the analog input pin that we use for the potentiometer
   - BTNLINPIN        A1  pin to which the button line (4 buttons) is connected to
   - LOWBATPIN         A2  the pin on which the powerboost 1000c indicates a low baterry - not functional
   - IRREMOTEPIN       A3  the pin on which the IR Remote Receiver is connected to
   - programming       A4  the pin the program button is connected to. The program 
                           button changes the functionality of the overall program in 
                           that (if pressed) the code will register a new tag for use with 
                           an album directory currently not connected to a tag 
                           Functionality yet to come!
   
   
   Configuration
   ---------------------------------------------------------------------------------------
   Some features (as e.g. Remote Control, Buttons or operation LED etc.) can be turned off 
   or on via #define switches in the code below.
   
      IRREMOTE          enables the IR Remote Control option
      
      BUTTONS           enables the 4 control buttons
      
      VOLUMEPOT         enables the volume potentiometer
      
      LOWBAT            enables the pin to read about low battery warnings from the adafruit powerboost 1000c

                        
                        YOU CAN ONLY EITHER ACTIVATE THE LEDs OR THE LEDMATRIX
                        
      OPRLIGHT          enables the operations light on the front of the box
      
      OPRLIGHTTIME      enables time based operations light - turns off the light after 30 Minutes

      INFOLED           enables a warning and an error led
      
      LEDMATRIX         enables the 8x8 LED Matrix to display working parameter

      
      SPEEDMASTER_PN532 enables the use of the Speedmaster library for the PN532 board
      
      ADAFRUIT_PN532    enables the use of the Adafruit library for the PN532 board
      
      NFCNDEF           enables the use of NDEF messages to get the directory for a tag
      
      NFCTRACKDB        enables the use of the TrackDB to get the directiry for a tag

      ALBUMNFC          enables a special file albumnfc.tdb in which all album <-> nfc
                        connections are stored - additional to the TrackDb files

      RESUMELAST        enables the option to resume last played album upon startup.
                        This is achieved via a file in the TrackDB and works without 
                        a tag but uses the pause/resume button instead 
      
      DISABLE_LOOPING   disables looping an album in case the figure is still on the 
                        reader when playback is finished
*/

//
//     CCCCC   OOOOOO   NN    NN  FFFFFF
//    CC      OO    OO  NNN   NN  FF
//    CC      OO    OO  NN NN NN  FFFF
//    CC      OO    OO  NN   NNN  FF
//     CCCCC   OOOOOO   NN    NN  FF
//
// make sure to comment this out before uploading in production as it turns on lots and lots of serial messages
// if it is not define, no Serial.print is possible, as also Serial.begin() is omitted
#define DEBUGOUT 1
// trace gives out even more info - does coszt quite some RAM so use with caution
//#define TRACEOUT 1
// to enable periodic output of free RAM during playBack, uncomment the following line.
//#define RAMCHECK 1


//
// turn ON / OFF certain hardware/software features
//
// if defined the box emits a sound whenever next / prev track or pause track is executed via buttons or ir remote
#define TONE_SIGNAL 1 

// to enable the IR Remote Control option uncomment the following line - does not work currently
//#define IRREMOTE 1

// to enable the control buttons uncomment the following and each corresponding line for the buttons
#define BUTTONS 1
#define VOLUP_BUTTON 1
#define VOLDOWN_BUTTON 1
#define NEXTTRACK_BUTTON 1
#define PREVTRACK_BUTTON 1
#define PAUSE_BUTTON 1
//#define LIGHT_BUTTON 1

// to enable the volume potentiometer uncomment the follwing line
//#define VOLUMEPOT 1

// to enable the low battery warning with light and voice uncomment the follwing line
//#define LOWBAT 1


//
// YOU CAN EITHER CONNECT AND USE THE INFO AND WARNING LEDS OR THE 8x8 LED MATRIX
//
// to enable the operations light on the front of the box, uncomment the following line
//#define OPRLIGHT 1
// to enable time based operations light - turns off the light after 30 Minutes - uncomment the following line
//#define OPRLIGHTTIME 1

// to enable the error and warning led, which is also used to indicate waiting for a tag, ucomment the next 
//#define INFOLED 1

// to enable the 8x8 LED Matrix uncomment the next
//#define LEDMATRIX 1


// Define the PN532 implementation
// ONLY ONE of these two can be used and additionally the first one is obligatory in case 
// you want to use   NFCNDEF   for tag <--> album connection. If you opt for the TrackDB for this connection 
// (with option NFCTRACKDB below) you may also try the Adafruit library - it will additionally give you 
// track absence detection and has a smaller memory footprint. 
#define SPEEDMASTER_PN532 1
//#define ADAFRUIT_PN532 1

// Define the NFC <-> Album connection implementation
// ONLY ONE of the following two options for the NFC reading and album <-> tag connection can be chosen

// to use NDEF to get the album directory directly from the tag, uncomment the following line
// this implementation uses the Speedmaster Library and Don's NDEF library to read NFC Tags and
// get the album directory that is stored as an NDEF Message on the tag. That means, it does NOT
// use the decribed TrackDB. It is also much heavier (in Progmem size) than the Adafruit PN532
// implementation and does NOT support recognition of a removed tag. 
#define NFCNDEF 1

// to use TrackDB to get the Tag UID and retrieve the directory from the trackDb, uncomment the following 
//#define NFCTRACKDB 1
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
void loop() {
  boolean weHaveATag = false;                     // set true if a tag is present
  boolean resumeLast = false;                     // set true if the pause button (also on IR Remote) is pressed without a tag present
  boolean loopWarningMessageNoAlbumInfos = true;  // make sure we get the "no album info on tag" message at least once
  boolean loopWarningMessageNoFilesInDir = true;  // make sure we get the "no files in dir" message at least once
  
  #ifdef DEBUGOUT
    Serial.print(F("."));
    #ifdef INFOLED
      if (loopLightHigh) {
        digitalWrite(WRNLEDPIN, LOW);
        loopLightHigh = false;
      } else {
        digitalWrite(WRNLEDPIN, HIGH);
        loopLightHigh = true;
      }
    #endif
  #endif

  
  
  // check for tag presence or if the user wants to resume the last album
  weHaveATag = checkForTagPresence();
  resumeLast = checkForResumeLast();
  
  // if a tag is found or the pause button is pressed without a tag, we continue
  if (weHaveATag || resumeLast) {
    #ifdef INFOLED
      digitalWrite(WRNLEDPIN, LOW);
      loopLightHigh = false;
    #endif
    
    #ifdef DEBUGOUT
      if (weHaveATag) Serial.println(F(" tag found! ")); else Serial.println(F(" resume last "));
    #endif
    
    // read data from tag: directory, track number and playing order.
    // sets the directpry to play (plrCurrentFolder) and the track to start playback with (firstTrackToPlay)
    if (!getDirAndTrackToPlay(weHaveATag)) {      // if passed true, the function will try to get the information from a tag, 
                                                  // on false, it will try to read the last played album file - only with TrackDb option
      
      // if we don't get at least a directory we can't start playback and inform the user
      if (loopWarningMessageNoAlbumInfos) {
        loopWarningMessageNoAlbumInfos = false;
        issueWarning("no album info", "/system00/nodircar.mp3", true);
      }
    } else {  // we may start playing as it seems
      // check if the current directory is the same as the plrLastFolder
      // if it is and looping is disabled, then we won't restart playback
      #ifdef DISABLE_LOOPING
        equal = true;
        for (byte i=0; i<8; i++) {
          #ifdef TRACEOUT
            Serial.print(" last: ");
            Serial.print(plrLastFolder[i]); 
            Serial.print(" / current: ");
            Serial.print(plrCurrentFolder[i]);
          #endif
          if ( plrLastFolder[i] != plrCurrentFolder[i] ) {
            #ifdef TRACEOUT
              Serial.println(F(" is a new tag"));
            #endif
            equal = false;
            break;
          }
        }
        if (!equal) {
      #endif
          // now let's get the number of files in the album directory
          uint8_t numberOfFiles = countFiles(SD.open(plrCurrentFolder));
          
          // there is no file in the folder indicate this as a minor error
          if (numberOfFiles < 1) {
            if (loopWarningMessageNoFilesInDir) {
              loopWarningMessageNoFilesInDir  = false; // set loop warning message so we don't show this warning in the next loop
              issueWarning("no files found", "/system00/nodirtag.mp3", true);
              #ifdef LEDMATRIX
                displayStuff(SADSD);
              #endif
            }
          } else {
            // check if the current directory as read from the tag is the same as the plrLastFolder
            // if NOT, put the current directory in the last directory played var so we can dcide later whether 
            // or not we want to loop the current album - as instructed per compile time define
            #ifdef DISABLE_LOOPING
              // first we check whether or not the two variables are different 
              equal = true;
              for (byte i=0; i<8; i++) {
                if ( plrLastFolder[i] != plrCurrentFolder[i] ) equal = false;
              }
              // and only in this case we set plrLastFolder to the value of plrCurrentFolder
              if (!equal) {
                memset(plrLastFolder, 0, sizeof(plrLastFolder));       // make sure var to hold path is empty
                strcat(plrLastFolder, plrCurrentFolder);               // and add the Directory to it
              }
            #endif
            
            char retVal = playAlbum(numberOfFiles);
            retVal = nextTrackToPlay;
            if (retVal < 0) { 
              issueWarning("playback failed", "/system00/playfail.mp3", true);
            } else {  
              #ifdef TRACEOUT
                Serial.println(F("\nplayback end"));
              #endif
              #ifdef DEBUGOUT
                #ifndef TRACEOUT
                  Serial.println(F("\n"));
                #endif
              #endif
              #ifdef INFOLED
                digitalWrite(WRNLEDPIN, LOW);
              #endif
            }
          } // end of check if at least 1 file was found
          
      // DISABLE LOOPING
      #ifdef DISABLE_LOOPING
        } else {
          #ifdef TRACEOUT
            Serial.println(F("same tag detected"));
          #endif
        }
      #endif
    } // end of directory plus track retrieved from nfc tag
    
    // finally turn off the info led
    #ifdef OPRLIGHT
      if (lightOn) digitalWrite(OPRLEDPIN, LOW);
    #endif
    
    // RESET THE NFC READER
    #ifdef NFCNDEF
      // this now clears the NFC reader so it will recognize a new tag again
      nfc.begin();
    #endif
  } // end of tag is present
  
  delay(1000); // throttle the loop for 1 second
  
  // check if the battery is still good
  #ifdef LOWBAT
    if (digitalRead(LOWBATPIN == LOW)) {
      if ((millis()-lowBatCheckTime > 300000)) {
        digitalWrite(ERRLEDPIN, HIGH);
        issueWarning("BATTERY LOW", "/system00/lowbat01.mp3", true);
        lowBatCheckTime = millis();
      }
    }
  #endif
} // end of loop
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

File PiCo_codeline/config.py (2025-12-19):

# config.py
from machine import Pin, I2C, SPI
import _thread

"""
        ┌────────── I²C1-BUS (OLED / RTC) ──────────────┐
        │                                               │
        │  ┌──────────────┐     ┌─────────────┐         │
        │  │ SH1106 OLED  │     │  DS3231 RTC │         │
        │  │  (addr 0x3C) │     │    (0x68)   │         │
        │  │              │     │             │         │
        │  │ SDA ◄────────┼─────┼─────────────┼───► SDA │
        │  │ SCL ◄────────┼─────┼─────────────┼───► SCL │
        │  │ VCC ◄────────┼─────┼─────────────┼───► 3V3 │
        │  │ GND ◄────────┼─────┼─────────────┼───► GND │
        │  │ IRQ ──(opt)  │     └─────────────┘         │
        │  └──────────────┘                             │
        └───────────────────────────────────────────────┘ 
            
         5V  ──► 5V  (NFC und Audio)
         3V3 ──► 3V3 (Poti, RTC und OLED)
         GND ──► GND (alle Module)
         
         Poti wiper ──► GP26 ADC0
         
         Buttons & Prog-Switch
         GP10 ── Play/Pause (BTN → GND, Pull-Up)
         GP11 ── Next       (BTN → GND, Pull-Up)
         GP12 ── Prev       (BTN → GND, Pull-Up)
         GP13 ── Stop       (BTN → GND, Pull-Up)
         GP28 ── Prog-Mode  (Swth→ GND, Pull-Up)
         
         OLED/RTC
         I2C 1 / Thread 0           
         SCL ──► GP3
         SDA ──► GP2
         
         
         Adafruit Music Maker / VS1053 Shield (mit microSD)
         SPI 0 / Thread 0
         SCK  VS1053 & SD D13 ◄─── GP18 (SPI0 SCK)
         MOSI VS1053 & SD D11 ◄─── GP19 (SPI0 MOSI)
         MISO VS1053 & SD D12 ◄─── GP16 (SPI0 MISO)
         MCS  VS1053 CS   D7  ───► GP5
         DCS  VS1053 DCS  D6  ───► GP6
         CCS  SD CS       D4  ───► GP8
         DREQ VS1053 DR   D3  ◄─── GP7
         RST                  ───► unused
         
         PN532 NFC Reader
         SPI 1 / Thread 1
         CS           ───► GP13
         RST          ───► None
         SCK          ◄─── GP10
         MOSI         ◄─── GP11 TX
         MISO         ◄─── GP12 RX
"""

# global debug output
_DEBUG_CNF = True
_DEBUG_MAIN = True
_DEBUG_CTRL = True
_DEBUG_AUDIO = False
_DEBUG_VOL = False
_DEBUG_NFC = False
_DEBUG_RTC = False
_DEBUG_DISP = False
_DEBUG_BTN = False
_DEBUG_STAT = True
_DEBUG_STOR = False
_DEBUG_WEB = False
_DEBUG_ID3 = False
_DEBUG_TRIG = False

# Texte
oled_text = {"PLAY": "Play >"
             , "PAUSE": "Pause ="
             , "STOP": "Stop"
             , "PREV": "Prev <"
             , "NEXT": "Next >"
             , "VOL_UP": "Volume +"
             , "VOL_DWN": "Volume -"
             , "SHOW_TAG": "Show Tag to play"
             , "WELCOME": "Welcome"
             , "STARTING": "Starting player..."
             , "NO_ALBUM": "No Album found"
             , "NFC_INIT": "Init NFC"
             , "NFC_ERR": "NFC Reader Fail"
             , "NFC_ERR_2": "Board not found"
             , "NFC_OK": "NFC Init done"
             , "AUDIO_INIT": "Init Player"
             , "AUDIO_ERR": "Player Failure"
             , "PROG_MODE": "Prog Mode"
             , "PROG_MODE_OFF": "Closing Prog Mode"
             , "WIFI_CON": "connecting wifi..."
             , "WIFI_FAIL": "connect error"
             , "RTC_INIT": "Init RTC"
             , "RTC_ERR": "RTC Failure"
             , "VOLUME": "Volume"
             }

def t(key: str, default: str = "") -> str:
    """Zentraler Zugriff auf UI-Texte."""
    return oled_text.get(key, default or key)


# config.py
AUDIO_IMPL   = "VS1053"    # Audio Backends:   VS1053, dfplayer, wav_pwm oder mock
SD_IMPL      = "sd"        # SD Backends:      sd oder mock
DISPLAY_IMPL = "sh1106"    # Display Backends: lcd1602, sh1106, ssd1306, tft oder mock
NFC_IMPL     = "pn532_spi" # NFC Backends:     pn532_spi oder mock
RTC_IMPL     = "ds3231"    # RTC Backends:     ds3231 oder mock
VOLUME_IMPL  = "poti"      # Volume backend:   poti, buttons / btn / key oder mock
PROG_MODE_SOURCE = "inactive"   # can either be pin, active (mocked active) or inactive (mocked inactive)

start_sleep_ms = 5000 # number of milliseconds the main rountine shall wait before initializing all the hardware

# --- WLAN / Upload ---
# ssid und password fürdas wlan finden sich in secrets.py:
# WIFI_SSID="my_wlan"
# WIFI_PASS="my_wifi_pass"
#
try:
    from secrets import (
                        WIFI_SSID,
                        WIFI_PASS
                        )
except ImportError:
    WIFI_SSID = None
    WIFI_PASS = None
    
WIFI_ENABLED   = False 
UPLOAD_ENABLED = False 
UPLOAD_PORT    = 80


# ---------- I2C für Display und RTC GP2/GP3 ----------
I2C_RTC_OLED_ID = 1
I2C_RTC_OLED_SCL = 3   # GP3
I2C_RTC_OLED_SDA = 2   # GP2
I2C_RTC_OLED_FREQ = 400_000
# I2C-Bus aufbauen (gemeinsam für RTC/Display)
i2c = I2C(I2C_RTC_OLED_ID, scl=Pin(I2C_RTC_OLED_SCL), sda=Pin(I2C_RTC_OLED_SDA), freq=I2C_RTC_OLED_FREQ)
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

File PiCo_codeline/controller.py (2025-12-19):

# controller.py
import utime
import json
try:
    import _thread
except Exception:
    _thread = None

from config import (
                    PROG_MODE_SOURCE
                    , _DEBUG_CTRL as _DEBUG
                    , _USE_ID3_TAG
                    , t
                    )

import id3  # für ID3-Tags

class PlayerController: 
    def __init__(self
                 , display
                 , audio
                 , storage
                 , rtc
                 , buttons
                 , triggers
                 , volume):
        self.audio = audio
        self.display = display
        self.rtc = rtc
        self.volume = volume
        self.triggers = triggers or []
        self.storage=storage
        
        self.play_state = "IDLE"
        self.resume_state = {}    # für UID-State
        self.current_uid = None
        self.track_files = []
        self.track_index = 0
        self.offset = 0
        
        self._last_vol_set_ms = 0
        self._last_vol_pct = None
        
        # Display/meta
        self.meta = {"title": "", "album": "", "artist": "", "track": ""} if _USE_ID3_TAG else None
        
        # Timing / UI updates
        self._last_clock_s = -1
        self._last_progress_ms = 0
        self._last_progress_pct = None
        
        # --- audio thread safety / multicore feed support ---
        self._audio_lock = _thread.allocate_lock() if _thread else None
        
        # --- lazy id3 support ---
        self._id3_pending_path = None
        self._id3_pending_set_ms = 0
        
        # init clock display immediately
        self._update_clock(force=True)
        
    # -------------------------------------------------
    # Hauptloop (Single Thread)
    # -------------------------------------------------
    def loop(self):
        # Core0 macht UI/Trigger/Clock/Volume + Progress read-only
        if self.play_state == "PLAY":
            self._update_progress_only()
            self._maybe_load_id3_lazy()
        
        self._handle_triggers()
        self._update_clock()
        self._apply_volume_if_changed()
        
        utime.sleep_ms(2)
    
    def loop_audio_only(self):
        """
        Für Core1: nur VS1053 füttern. KEIN Display, KEINE Trigger.
        """
        if self.play_state != "PLAY":
            # Im Idle/Stop/Pause: NICHT spammen und CPU schonen
            utime.sleep_ms(20)   # << wichtig: entlastet massiv
            return
        self._audio_lock_acquire()
        try:
            self.audio.feed()
        except Exception:
            pass
        finally:
            self._audio_lock_release()
    
    def stop(self):
        # entspricht STOP-Trigger
        self._handle_stop()
    def start(self, uid):
        # entspricht START-Trigger
        self._handle_start(uid)
    
    # -------------------------------------------------
    # Trigger-Verarbeitung
    # -------------------------------------------------
    def _handle_triggers(self):
        for trg in self.triggers:
            try:
                ev = trg.poll(self.play_state)
            except TypeError:
                ev = trg.poll()
            
            if not ev:
                continue
            
            kind, value = ev
            
            if kind == "start":
                self._handle_start(value)
                return
            if kind == "stop":
                self._handle_stop()
                return
            if kind == "play_pause":
                self._pause_toggle()
                return
            if kind == "next":
                self._next_chapter()
                return
            if kind == "prev":
                self._prev_chapter()
                return
    
    def _handle_start(self, uid):
        if self.play_state == "PLAY":
            return
        self.current_uid = uid
        if not self._load_book(uid):
            if _DEBUG: print("[CTRL] Error: no content for uid found")
            self.display.show_status("No Content", uid)
            return
        
        self._start_play(resume=True)
    
    def _handle_stop(self, show_idle=True):
        if self.play_state == "PLAY":
            self._stop_play()
        
        if show_idle:
            self.display.show_idle(t("WAIT_FOR_TAG", "Show Tag to play"))
    
    # ----------------------------
    # Storage + state + chapters
    # ----------------------------
    def _chapters_for(self, uid):
        """Return (album_dir, [chapter_filenames]) for a given uid."""
        album_dir, tracks = self.storage.list_tracks_for_uid(uid, exts=(".mp3",))
        #album_dir, files = self._list_tracks_for_uid(uid, exts=(".mp3",))
        #if not tracks:
        #    return album_dir, []
        #
        # sort by numeric prefix if possible, otherwise by name
        #def num_key(name):
        #    try:
        #        return int(name.split(".", 1)[0])
        #    except Exception:
        #        return 999999
        #
        #files_sorted = sorted(tracks, key=lambda f: (num_key(f), f))
        return album_dir, tracks
    
    def _load_book(self, uid):
        album_dir, chapters = self._chapters_for(uid)
        if not chapters:
            if _DEBUG: print("[CTRL] No album for uid:", uid)
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

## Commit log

2016-09-05 added file extensions for cover and audio files added read new rfid and populate db function added test mp3 added shutdown script
    [inlet_with_screen.skp, inlet_with_screen~.skp]
2017-10-30 added API-prefix to all rest endpoints and redirects in case user forgets to provide it
2017-10-31 removed old tag data and sample audiobook
2017-11-05 changed absolute path to allow for /data/Media on raspberry Pi target
2017-11-05 renaming directories to all lower case
2017-11-11 player now gets track data from rest call to app.js
2017-11-19 added new python program to drive tripple led
2017-11-19 fixed typo in pin assignment
    [cycLED.py]
2017-11-19 changed pin numbering of red
2017-11-19 fixed typo in url
    [cycLED.py]
2017-11-19 bugfixing in function calls
    [cycLED.py]
2017-11-19 added led controller skeleton
2017-11-25 added ascii art to ledservice
2017-11-26 Visualisierung der PIN-Belegung
    [RPI Pinbelegung.xlsx]
2018-01-18 Major project-refactoring including switch to Arduino
2018-01-18 moved raspberry pi stuff to sub directory
2018-01-18 rewrote README.md to reflect switch to Arduino
2018-02-14 codeline rewritten to employ TrackDb and README.md rewritten for step by step instructions
    [RPI Pinbelegung.xlsx]
2018-02-15 control buttons now functional
    [RPI Pinbelegung.xlsx]
2018-02-21 codeline fairytale 2a is functional with buttons
2018-02-21 added example content to be placed on sd-card
    [Fairytale.fzz]
2018-02-22 added schematics for ir-module
    [RPI Pinbelegung.xlsx]
2018-02-22 changed message to inform user to turn off the arduino
2018-02-27 bug fixed check on IRRemote resume last call
    [fairytale23.ino]
2018-02-27 low battery check now only uses time to decide whether or not voice the message
2018-02-27 bugfixing count of number of files
    [fairytale23.ino]
2018-02-27 new config switches for VS1053 and SD-Card
2019-01-24 switched pause and light button and fixed tag looping
    [fairytale25.ino]
2019-01-24 explained DISABLE_LOOPING switch in description section
2019-01-25 bugfix for checkAndSetCurTrack to pass numberOfFiles
    [fairytale25.ino]
2019-01-26 rework for TrackDB started - new defines to choose between ADAFRUIT and SPEEDMASTER PN532 library
    [createTrackDb.ino, fairytale25.ino, getTagUids.ino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]
2020-06-11 codeline 27 is functiomnal with 8x8 led matrix
2025-12-16 PiCo Codeline release 1.0 with functional Music Maker, ID3, NFC, Display, RTC, HTTP-Interface
2025-12-18 http_server creates index file / controller using 2 threads for playback and everything else
2025-12-19 ntroduced spi-locking mechanism so that sd and vs1053 do not intefere with one another
